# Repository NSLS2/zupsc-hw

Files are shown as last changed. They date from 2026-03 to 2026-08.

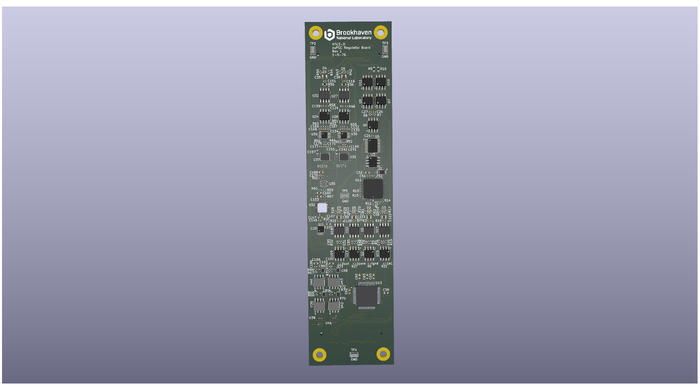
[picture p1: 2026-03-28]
daughter/rev2/psc_daughter_brd.png

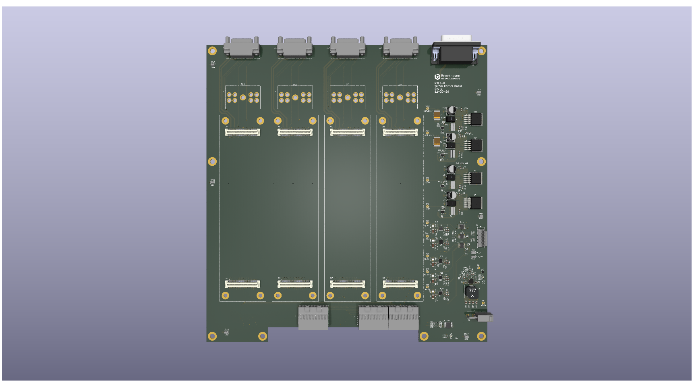
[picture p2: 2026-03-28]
carrier/revA/psc_carrier_brd.png

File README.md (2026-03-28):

# ZuPSC – NSLS-II Power Supply Controller

The **ZuPSC** is the next-generation NSLS-II Power Supply Controller built on a Zynq UltraScale+ FPGA platform. It combines FPGA-based real-time control with embedded software to deliver high-performance regulation, data acquisition, and system diagnostics.
<p align="center">
  <br>
  <em>ZuPSC chassis showing FPGA processing board and channel electronics</em>
</p>

---

## Overview

- **FPGA (PL)**  
  - Executes PID control loops at the sample rate  
  - Handles high-speed data acquisition  
  - Implements interlock and protection logic  

- **ARM Processor (PS)**  
  - Runs a server interface  
  - Communicates with a custom EPICS driver  
  - Provides control, monitoring, and diagnostics over the controls network  

---

## System Architecture

The ZuPSC chassis is composed of three primary circuit boards:

### 1. FPGA Processing Board (zuDFE)
- NSLS-II standard processing platform  
- Digital I/O and GPIO handling  
- ADC data acquisition  
- 20-bit precision DAC output  
- PID control loop execution in FPGA fabric  
- High-speed and low-speed communication:
  - Ethernet
  - Fiber links  
- Embedded Event Receiver (EVR)
  - Compatible with 2.5 Gbps MRF Event Generator (EVG)

---

### 2. Carrier Board
- Interfaces FPGA processing board to channel electronics  
- Routes signals between digital and analog domains  
- Provides system-level connectivity  

---

### 3. Channel Electronics Board
- Precision analog front-end  
- **20-bit DAC** for power supply command output  
- **Dual 20-bit ADCs** for DCCT readback  
- **4× 16-bit ADCs** for auxiliary monitoring  
- Isolated digital I/O channels  

---

## Key Features

- Real-time PID control implemented in FPGA  
- High-resolution (20-bit) DAC/ADC signal chain  
- Deterministic timing via embedded EVR  
- Integrated interlock and protection logic  
- EPICS-compatible control interface  
- Modular 3-board architecture  

---

## Intended Use

The ZuPSC is designed for high-performance accelerator power supply control applications at NSLS-II, where deterministic timing, precision measurement, and reliable interlocks are critical.

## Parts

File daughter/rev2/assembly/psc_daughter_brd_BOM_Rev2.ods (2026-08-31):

zuPSC Daughter Board Rev2
Parts per Board |  | 338
Total Parts Cost |  | $561.68
Do not install parts in red
Line Item | Qty per Board | Unit Cost | Cost Per Board | Part Number | Reference Designator | Value | Description | Manufacturer | DNP
1 | 3 | $0.01 | $0.03 | C0402C100K5RACTU | C21,C26,C27 | 10pF | CAP CER 10PF 50V X7R 0402 | Kemet
2 | 4 | $0.01 | $0.04 | C0402C221K5RACTU | C1,C68,C78,C88 | 220pF | CAP CER 220PF 50V X7R 0402 | Kemet
3 | 4 | $0.01 | $0.04 | GRM1555C1H471FA01D | C120,C122,C128,C129 | 470pF | CAP CER 470PF 50V C0G/NP0 1% 0402 | Kemet
4 | 2 | $0.90 | $1.80 | C0603C202F5GACTU | C111,C112 | 2nF | 2000pF CAP CER 0603 50V 1% NP0/C0G | Kemet
5 | 6 | $0.22 | $1.32 | EMCT101W222M1GV001E | C35,C38,C101,C103,C105,C107 | 2200pF | CAP CER 2200PF 100V X7R 0805 FEED THROUGH | Johanson Dielectrics
6 | 2 | $0.14 | $0.28 | C0603C302J5GACTU | C109,C110 | 3nF | CAP CER 3000PF 25V C0G/NP0 0603 | Murata
7 | 4 | $0.01 | $0.04 | CL05B332KB5NNNC | C116,C141,C151,C176 | 3300pF | CAP CER 3300PF 50V X7R 0402 | Samsung
8 | 4 | $0.01 | $0.04 | CL05B472KB5NNNC | C8,C75,C85,C95 | 4700pF | CAP CER 4700PF 50V X7R 0402 | Samsung
9 | 4 | $0.01 | $0.04 | CL05B682KB5NNNC | C138,C140,C142,C177 | 6800pF | CAP CER 6800PF 50V X7R 0402 | Samsung
10 | 1 | $0.01 | $0.01 | GRM155R71E473KA88D | C132 | 47nF | CAP CER 47nF 25V X7R 0402 | Murata
11 | 85 | $0.01 | $0.85 | TMK105BJ104KV-F | C4,C5,C9,C10,C13,C14,C16,C19,C20,C24,C25,C29,C34,C36,C37,C39,C44,C45,C46,C47,C48,C50,C51,C53,C54,C55,C56,C58,C64,C65,C67,C71,C72,C76,C77,C81,C82,C86,C87,C91,C92,C96,C97,C99,C102,C104,C108,C113,C115,C117,C123,C124,C126,C130,C134,C137,C144,C146,C148,C149,C150,C152,C158,C159,C163,C164,C165,C168,C170,C173,C174,C175,C179,C181,C182,C183,C184,C185,C186,C189,C190,C191,C192,C193,C196 | 0.1uF | CAP CER 0.1UF 25V X5R 0402 | Taiyo Yuden
12 | 1 | $0.01 | $0.01 | CL10B105KA8NNNC | C49 | 1uF | CAP CER 1UF 25V X7R 0603 | Samsung
13 | 1 | $0.18 | $0.18 | CGA4J1X7R1H475K125AC | C131 | 4.7uF | CAP CER 4.7UF 50V X7R 0805 | Samsung
14 | 74 | $0.07 | $5.18 | CL10A106MA8NRNC | C2,C3,C6,C7,C11,C12,C15,C17,C18,C22,C23,C28,C30,C31,C32,C33,C40,C41,C42,C43,C52,C57,C59,C60,C61,C62,C63,C66,C69,C70,C73,C74,C79,C80,C83,C84,C89,C90,C93,C94,C98,C100,C106,C114,C118,C119,C121,C125,C127,C133,C136,C139,C143,C145,C147,C153,C154,C155,C156,C157,C160,C161,C162,C166,C167,C169,C171,C172,C178,C180,C187,C188,C194,C195 | 10uF | CAP CER 10UF 25V X5R 0603 | Samsung
15 | 1 | $0.62 | $0.62 | MSAST32MAB5476MPNDT1 | C135 | 47uF | CAP CER 047UF 25V X5R 1210 | Taiyo Yuden
16 | 2 | $2.53 | $5.06 | 61082-061400LF | J1,J2 |  | CONN RCPT 60POS SMD GOLD | Amphenol
17 | 1 | $0.23 | $0.23 | DFLS130-7 | D1 |  | DIODE SCHOTTK 30V 1A POWERDI 123 | Diodes Inc.
18 | 2 | $34.72 | $69.44 | LTC2376CDE-20#PBF | U31,U37 |  | IC ADC 20BIT SAR 16DFN | Analog Devices
19 | 1 | $125.06 | $125.06 | ADR1001AEZ | U12 |  | IC VREF SERIES 5V 0.25% 20CLCC | Analog Devices
20 | 3 | $4.51 | $13.53 | LT6202CS5#TRPBF | U22,U24,U35 |  | IC OPAMP GP 1 CIRCUIT TSOT23-5 | Analog Devices
21 | 1 | $14.02 | $14.02 | LTC6655BHLS8-5#PBF | U32 |  | IC VREF SERIES 0.025% 8CLCC | Analog Devices
22 | 2 | $0.77 | $1.54 | TXUN0104RUTR | U38,U41 |  | IC XLTR VL UNIDIR 12-UQFN | TI
23 | 1 | $25.17 | $25.17 | ADS8568SPM | U13 |  | IC ADC 16BIT SAR 64LQFP | Analog Devices
24 | 2 | $6.81 | $13.62 | ADUM5240ARZ | U39,U40 |  | DGTL ISOLTR 2.5KV 2CH GP 8-SOIC | Analog Devices
25 | 2 | $6.81 | $13.62 | ADUM5242ARZ | U42,U43 |  | DGTL ISOLTR 2.5KV 2CH GP 8-SOIC | Analog Devices
26 | 1 | $2.72 | $2.72 | ADA4523-1BRMZ | U23 |  | IC OPAMP ZER-DRIFT 1CIRC 8MSOP | Analog Devices
27 | 4 | $10.23 | $40.92 | AD8221BRZ | U1,U14,U16,U18 |  | IC INST AMP 1 CIRCUIT 8SOIC | Analog Devices
28 | 2 | $12.76 | $25.52 | AD8429BRZ | U27,U33 |  | IC INST AMP 1 CIRCUIT 8SOIC | Analog Devices
29 | 2 | $3.46 | $6.92 | THP210DR | U21,U26 |  | IC OPAMP DIFF 1 CIRCUIT 8SOIC | TI
30 | 4 | $0.65 | $2.60 | SP3006-02XTG | CR5,CR6,CR7,CR8 |  | TVS DIODE 6VWM 15VC SOT563 | Littlefuse
31 | 6 | $0.24 | $1.44 | SP3118-01ETG | D2,D3,D4,D5,D6,D7 |  | TVS DIODE 18VWM 38VC SOD882 | Littlefuse
32 | 4 | $0.23 | $0.92 | RCS-0C | TP2,TP3,TP4,TP5 |  | PC TEST POINT NATURAL | TE
33 | 1 | $4.96 | $4.96 | LT3042EMSE#TRPBF | U20 |  | IC REG LINEAR POS ADJ 10MSOP-EP | Analog Devices
34 | 6 | $2.66 | $15.96 | OPA277UA/2K5 | U2,U7,U9,U15,U17,U19 |  | IC OPAMP GP 1 CIRCUIT 8SOIC | Analog Devices
35 | 1 | $3.93 | $3.93 | AD8676ARZ-REEL7 | U3 |  | IC OPAMP GP 2 CIRCUIT 8SOIC | Analog Devices
36 | 2 | $5.91 | $11.82 | AD8676BRZ | U4,U8 |  | IC OPAMP GP 2 CIRCUIT 8SOIC | Analog Devices
37 | 1 | $13.75 | $13.75 | AD797ARZ | U6 |  | IC OPAMP GP 1 CIRCUIT 8SOIC | Analog Devices
38 | 2 | $2.99 | $5.98 | BUF634AIDR | U10,U11 |  | IC OPAMP GP 1 CIRCUIT 8SOIC | Analog Devices
39 | 1 | $129.29 | $129.29 | AD5791BRUZ | U5 |  | IC DAC 20BIT V-OUT 20TSSOP | Analog Devices
40 | 2 | $0.10 | $0.20 | BAT54S | D8,D9 |  | DIODE ARR SCHOTT 30V 200MA SOT23 | Diotec Semi
41 | 2 | $0.07 | $0.14 | LTST-C191KGKT | D10,D11 |  | LED GREEN CLEAR SMD | Lite-On Inc.
42 | 5 | $0.01 | $0.05 | ERJ-2GE0R00X | R15,R49,R79,R82,R83 | 0 | RES SMD 0 OHM JUMPER 1/10W 0402 | Panasonic
43 | 1 | $0.28 | $0.28 | RNCA0805BTS2K00 | R76 | 2 | RES 0805 2 OHM 0.1% | Stackpole
44 | 4 | $0.01 | $0.04 | ERJ-2RKF10R0X | R3,R18,R24,R30 | 10 | RES SMD 10 OHM 1% 1/10W 0402 | Panasonic | DNP
45 | 7 | $0.01 | $0.07 | ERJ-2RKF10R0X | R6,R12,R21,R27,R33,R61,R80 | 10 | RES SMD 10 OHM 1% 1/10W 0402 | Panasonic
46 | 4 | $0.01 | $0.04 | ERJ-2RKF30R1X | R52,R53,R64,R65 | 30.1 | RES SMD 30.1 OHM 1% 1/10W 0402 | Panasonic
47 | 2 | $0.01 | $0.02 | ERJ-2RKF15R0X | R9,R10 | 100 | RES SMD 100 OHM 1% 1/3W 0603 | Panasonic
48 | 1 | $0.01 | $0.01 | ERJ-2RKF1200X | R11 | 120 | RES SMD 120 OHM 1% 1/10W 0402 | Panasonic
49 | 2 | $0.32 | $0.64 | RQ73C1J665RBTD | R36,R56 | 665 | RES 665 OHMS 0.1% 0.15W 0603 | TE
50 | 1 | $0.38 | $0.38 | ERA-2ARB751X | R74 | 750 | RES SMD 750 OHM 0.1% 1/16W 0402 | Panasonic
51 | 12 | $0.01 | $0.12 | ERJ-2RKF1001X | R1,R2,R16,R17,R22,R23,R28,R29,R42,R43,R54,R55 | 1.0K | RES SMD 1K OHM 1% 1/10W 0402 | Panasonic
52 | 1 | $0.38 | $0.38 | ERA-2ARB102X | R50 | 1K | RES SMD 1K OHM 0.1% 1/16W 0402 | Panasonic
53 | 2 | 0.01 | $0.02 | ERJ-2RKF2200X | R57,R84 | 2.2K | RES SMD 220 OHM 1% 1/10W 0402 | Panasonic
54 | 8 | $0.01 | $0.08 | ERJ-2RKF2491X | R66,R67,R68,R69,R70,R71,R72,R73 | 2.49K | RES SMD 2.49K OHM 1% 1/10W 0402 | Panasonic
55 | 2 | $0.01 | $0.02 | ERJ-2RKF5111X | R7,R8 | 5.11K | RES SMD 5.11K OHM 1% 1/10W 0402 | Panasonic
56 | 1 | $0.38 | $0.38 | ERA-2ARB5621X | R75 | 5.62k | RES SMD 5.62KOHM 0.1% 1/16W 0402 | Panasonic
57 | 8 | $0.01 | $0.08 | ERJ-2RKF1002X | R4,R5,R19,R20,R25,R26,R31,R32 | 10K | RES SMD 10K OHM 1% 1/10W 0402 | Panasonic
58 | 19 | $0.01 | $0.19 | RT0603BRB0710KL | R35,R37,R38,R39,R40,R41,R44,R45,R46,R47,R48,R51,R58,R59,R60,R62,R63,R77,R78 | 10.0K | RES SMD 10K OHM 0.1% 1/10W 0603 | Yageo
59 | 1 | $0.01 | $0.01 | ERA-3ARB203V | R81 | 20.0K | RES SMD 20K OHM 0.1% 1/10W 0603 | Panasonic
60 | 1 | $0.01 | $0.01 | ERJ-2RKF6342X | R13 | 63K | RES SMD 63.4K OHM 1% 1/10W 0402 | Panasonic | DNP
61 | 1 | $0.01 | $0.01 | ERJ-2RKF7872X | R14 | 78.7K | RES SMD 78.7K OHM 1% 1/10W 0402 | Panasonic
62 | 1 | $0.01 | $0.01 | ERJ-2RKF1213X | R34 | 121K | RES SMD 121K OHM 1% 1/10W 0402 | Panasonic

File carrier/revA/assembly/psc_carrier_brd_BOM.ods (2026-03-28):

zuPSC Carrier Board
Parts Per Board |  | 216
Total Parts Cost |  | $304.54
Line Number | Qty per Board | Unit Cost | Cost Per Board | Part Number | Reference | Value | Description | Manufacturer
1 | 4 | $6.06 | $24.24 | LT3045EDD#TRPBF | U7,U8,U9,U10 |  | IC REG LIN POS ADJ 500MA 10DFN | Analog Devices
2 | 4 | $2.01 | $8.04 | LT6106CS5#TRMPBF | U4,U5,U21,U22 |  | IC CURR SENSE 1 CIRCUIT TSOT23-5 | Analog Devices
3 | 2 | $6.46 | $12.92 | LT3015EQ-15#PBF | U3,U20 |  | IC REG LINEAR -15V 1.5A DDPAK-5 | Analog Devices
4 | 2 | $5.57 | $11.14 | LT1963AEQ#TRPBF | U2,U19 |  | IC REG LIN POS ADJ 1.5A DDPAK-5 | Analog Devices
5 | 4 | $0.00 | $0.00 | BNL | U15,U16,U17,U18 |  | Burden Resistor Daughterboard | BNL
6 | 3 | $9.38 | $28.14 | LTC2991CMS#TRPBF | U12,U13,U14 |  | IC MONITOR OCTAL 16MSOP | Analog Devices
7 | 1 | $0.37 | $0.37 | CD74HC4050PWR | U23 |  | IC BUFFER NON-INVERT 6V 16-TSSOP | TI
8 | 1 | $9.56 | $9.56 | LT8643SEV#PBF | U11 |  | IC REG BUCK ADJ 6A 24LQFN | Analog Devices
9 | 1 | $5.79 | $5.79 | LT3015EDD#PBF | U6 |  | IC REG LINEAR NEG ADJ 1.5A 8-DFN | Analog Devices
10 | 1 | $1.78 | $1.78 | 3-641215-6 | U1 |  | CONN HEADER VERT 6POS 2.54MM | TE
11 | 8 | $0.23 | $1.84 | RCS-0C | TP12,TP13,TP14,TP15,TP16,TP17,TP18,TP19 |  | PC TEST POINT NATURAL | TE
12 | 11 | $0.00 | $0.00 | N/A | TP1,TP2,TP3,TP4,TP5,TP6,TP7,TP8,TP9,TP10,TP11 |  | TEST POINT | N/A
13 | 6 | $0.01 | $0.06 | ERJ-2RKF4991X | R9,R10,R48,R49,R58,R59 | 4.99K | RES SMD 4.99K OHM 1% 1/10W 0402 | Panasonic
14 | 11 | $0.01 | $0.11 | ERJ-2RKF1002X | R60,R61,R62,R63,R64,R65,R66,R67,R68,R69,R70 | 10K | RES SMD 9.53K OHM 1% 1/10W 0402 | Panasonic
15 | 3 | $0.01 | $0.03 | ERJ-2RKF9531X | R42,R44,R46 | 9.53K | RES SMD 9.53K OHM 1% 1/10W 0402 | Panasonic
16 | 4 | $0.71 | $2.84 | KRL6432E-M-R010-F-T1 | R4,R7,R53,R56 | 0.01 | RES 0.01 OHM 3W 2512 WIDE | Susumu
17 | 6 | $0.01 | $0.06 | ERJ-2RKF9091X | R36,R38,R40,R43,R45,R47 | 9.09K | RES SMD 9.09K OHM 1% 1/10W 0402 | Panasonic
18 | 2 | $0.01 | $0.02 | ERJ-2RKF4701X | R31,R32 | 4.7K | RES SMD 4.7K OHM 1% 1/10W 0402 | Panasonic
19 | 8 | $0.01 | $0.08 | ERJ-2RKF1000X | R3,R5,R6,R8,R52,R54,R55,R57 | 100 | RES SMD 100 OHM 1% 1/10W 0402 | Panasonic
20 | 2 | $0.01 | $0.02 | ERJ-2RKF1022X | R29,R35 | 10.2K | RES SMD 10.2K OHM 1% 1/10W 0402 | Panasonic
21 | 7 | $0.01 | $0.07 | ERJ-2RKF1001X | R2,R16,R27,R37,R39,R41,R51 | 1.0K | RES SMD 1K OHM 1% 1/10W 0402 | Panasonic
22 | 5 | $0.38 | $1.90 | KRL2012E-M-R220-F-T5 | R13,R14,R19,R22,R25 | 0.22 | RES 0.22 OHM 1W 0805 WIDE | Susumu
23 | 5 | $0.01 | $0.05 | ERJ-2GE0R00X | R11,R17,R20,R23,R33 | 0 | RES SMD 0 OHM JUMPER 1/10W 0402 | Panasonic
24 | 3 | $0.01 | $0.03 | ERJ-2RKF1152X | R1,R15,R50 | 11.5K | ERJ-2RKF1152X | Panasonic
25 | 1 | $0.01 | $0.01 | ERJ-2RKF1600X | R71 | 160 | RES SMD 160 OHM 1% 1/10W 0402 | Panasonic
26 | 1 | $0.01 | $0.01 | ERJ-2RKF4222X | R34 | 42.2K | RES SMD 42.2K OHM 1% 1/10W 0402 | Panasonic
27 | 1 | $0.01 | $0.01 | ERJ-2RKF1131X | R30 | 1.13K | RES SMD 1.13K OHM 1% 1/10W 0402 | Panasonic
28 | 1 | $0.01 | $0.01 | ERJ-2RKF8451X | R28 | 8.45K | RES SMD 8.45K OHM 1% 1/10W 0402 | Panasonic
29 | 1 | $0.01 | $0.01 | ERJ-2RKF4122X | R26 | 41.2K | RES SMD 41.2K OHM 1% 1/10W 0402 | Panasonic
30 | 1 | $0.01 | $0.01 | ERJ-2RKF2492X | R24 | 24.9K | RES SMD 24.9K OHM 1% 1/10W 0402 | Panasonic
31 | 1 | $0.01 | $0.01 | ERJ-2RKF1802X | R21 | 18.0K | RES SMD 18K OHM 1% 1/10W 0402 | Panasonic
32 | 1 | $0.01 | $0.01 | ERJ-2RKF3322X | R18 | 33.2K | RES SMD 33.2K OHM 1% 1/10W 0402 | Panasonic
33 | 1 | $0.01 | $0.01 | ERJ-2RKF5362X | R12 | 53.6K | RES SMD 53.6K OHM 1% 1/10W 0402 | Panasonic
34 | 1 | $0.10 | $0.10 | NX7002BKWX | Q1 |  | MOSFET N-CH 60V 270MA SOT323 | Nexperia
35 | 5 | $0.01 | $0.05 | LSMGG160808T331RG | L1,L2,L3,L4,L5 |  | FERRITE BEAD 330 OHM 0603 1LN | Taiyo Yuden
36 | 1 | $3.26 | $3.26 | MSS1048-222NLC | L6 | 2.2uF | FIXED IND 2.2UH 9.78A 7.2MOHM SM | Coilcraft
37 | 4 | $17.82 | $71.28 | 836149012 | J8,J11,J14,J17 |  | CONN MICRO-D PLUG 25POS R/A SLDR | Molex
38 | 8 | $2.81 | $22.48 | 61083-061402LF | J5,J6,J9,J10,J12,J13,J15,J16 |  | CONN PLUG 60POS SMD GOLD | Amphenol
39 | 3 | $17.37 | $52.11 | 6469028-1 | J1,J2,J3 |  | CONN RCPT HIGH SPEED 60P EDGE MT | TE
40 | 1 | $24.50 | $24.50 | 1731130154 | J7 |  | CONN D-SUB HD PLG 26POS R/A SLDR | Molex
41 | 1 | $1.25 | $1.25 | 39301022 | J4 |  | CONN HEADER R/A 2POS | Molex
42 | 2 | $0.77 | $1.54 | ASMDC300F/24-2 | F1,F2 |  | PTC RESET FUSE 24V 3A 2SMD | Littlefuse
43 | 2 | $0.10 | $0.20 | LTST-C191KGKT | D1,D3 | GREEN | LED GREEN CLEAR SMD | Lite-On Inc.
44 | 4 | $3.56 | $14.24 | T521X107M025ATE060 | C7,C8,C66,C67 | 100uF | CAP TANT POLY 100UF 25V 2917 | Kemet
45 | 4 | $0.04 | $0.16 | CL21A226MAYNNNE | C53,C54,C55,C56 | 22uF | CAP CER 22UF 25V X5R 0805 | Samsung
46 | 28 | $0.01 | $0.28 | TMK105BJ104KV-F | C5,C6,C10,C12,C13,C14,C15,C19,C21,C23,C24,C30,C31,C36,C37,C42,C43,C57,C58,C59,C64,C65,C69,C71,C72,C73,C74,C75 | 0.1uF | CAP CER 0.1UF 25V X5R 0402 | Taiyo Yuden
47 | 2 | $0.01 | $0.02 | CL10C100JB8NFNC | C48,C52 | 10pF | CAP CER 10PF 50V C0G/NP0 0603 | Samsung
48 | 25 | $0.04 | $1.00 | CL10A106MA8NRNC | C3,C4,C9,C11,C16,C17,C18,C20,C22,C25,C28,C29,C32,C34,C35,C38,C40,C41,C44,C47,C49,C62,C63,C68,C70 | 10uF | CAP CER 10UF 25V X5R 0603 | Samsung
49 | 5 | $0.22 | $1.10 | GRM31CR61A107MEA8L | C26,C27,C33,C39,C45 | 100uF | CAP CER 100UF 10V X5R 1206 | Murata
50 | 4 | $0.44 | $1.76 | EEE-FTH101XAP | C1,C2,C60,C61 | 100uF | CAP ALUM 100UF 20% 50V SMD | Panasonic
51 | 1 | $0.01 | $0.01 | CL10B105KA8NNNC | C51 | 1uF | CAP CER 1UF 25V X7R 0603 | Samsung
52 | 1 | $0.01 | $0.01 | CL10B331KB8NNNC | C50 | 330pF | CAP CER 330PF 50V X7R 0603 | Samsung
53 | 1 | $0.01 | $0.01 | CL10B223KB8NNNC | C46 | 0.022uF | CAP CER 0.022UF 50V X7R 0603 | Samsung

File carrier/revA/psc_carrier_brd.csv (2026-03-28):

Id | Designator | Footprint | Quantity | Designation | Supplier and ref
1 | C67,C66,C8,C7 | CAPMP7.6X4.3_4.3N_KEM | 4 | 100uF
2 | C61,C60,C1,C2 | CAP_EEFK_D8_PAN | 4 | 100uF
3 | U1 | 3-641215-6_TYC | 1 | 3-641215-6
4 | J1,J2,J3 | TE_6469028-1 | 3 | 6469028-1
5 | R16,R2,R51 | R_0402_1005Metric | 3 | 1.0K
6 | R13,R14,R22,R19,R25 | RESC1220X70N | 5 | KRL2012E-M-R220-F-T5
7 | U9,U7,U8,U10 | DFN-10-1EP_3x3mm_P0.5mm_EP1.65x2.38mm | 4 | LT3045xDD
8 | C20,C32,C3,C44,C16,C63,C28,C68,C18,C25,C41,C22,C17,C11,C29,C40,C70,C62,C35,C34,C4,C38,C9 | C_0603_1608Metric | 23 | 10uF
9 | L5,L2,L3,L1,L4 | IND_LSMG_160808_TAY | 5 | LSMGG160808T331RG
10 | R64,R66,R62,R69,R67,R61,R63,R60,R65,R68 | R_0402_1005Metric | 10 | 10K
11 | U19,U2 | TO-263-5_TabPin3 | 2 | LT1963AEQ
12 | R48,R58,R49,R10,R9,R59 | R_0402_1005Metric | 6 | 4.99K
13 | D1 | LED_0603_1608Metric | 1 | GREEN
14 | R27 | R_0402_1005Metric | 1 | 1k
15 | R26 | R_0402_1005Metric | 1 | 41.2k
16 | U17,U16,U15,U18 | burden | 4 | ~
17 | R15,R50,R1 | R_0402_1005Metric | 3 | 11.4K
18 | R28 | R_0402_1005Metric | 1 | 8.45k
19 | R33,R20,R23,R11,R17 | R_0402_1005Metric | 5 | 0
20 | R32,R31 | R_0402_1005Metric | 2 | 4.7k
21 | U13,U14,U12 | MSOP-16_MS | 3 | LTC2991CMS_TRPBF
22 | C31,C30,C65,C24,C6,C42,C10,C36,C37,C23,C21,C19,C12,C71,C5,C69,C64,C43,C58,C14,C75,C13,C72,C74,C15,C59,C73,C57 | C_0402_1005Metric | 28 | 0.1uF
23 | R56,R53,R4 | RES_6432_SUS | 3 | KRL6432E-M-R010-F-T1
24 | J15,J10,J9,J12,J5,J16,J13,J6 | AMPHENOL_61083-061402LF | 8 | 61083-061402LF
25 | R29,R35 | R_0402_1005Metric | 2 | 10.2k
26 | U11 | QFN-24-4EP_4x4mm_P0.5mm_EP1.125x1.125mm | 1 | LT8643S
27 | R12 | R_0402_1005Metric | 1 | 53K
28 | R36,R38,R45,R43,R47,R40 | R_0402_1005Metric | 6 | 9K
29 | R46,R42,R44 | R_0402_1005Metric | 3 | 9.56K
30 | C27,C33,C26,C39,C45 | C_1206_3216Metric | 5 | 100uF
31 | C48,C52 | C_0603_1608Metric | 2 | 10p
32 | R55,R54,R57,R5,R3,R8,R6,R52 | R_0402_1005Metric | 8 | 100
33 | TP2 | TestPoint_THTPad_D2.0mm_Drill1.0mm | 1 | +5.0V
34 | R34 | R_0402_1005Metric | 1 | 42.2k
35 | R39,R41,R37 | R_0402_1005Metric | 3 | 1K
36 | J11,J17,J14,J8 | 0836149012 | 4 | 0836149012
37 | U4,U21,U5,U22 | SOT-23-5 | 4 | LT6105
38 | C56,C54,C55,C53 | C_0805_2012Metric | 4 | 22u
39 | C46 | C_0603_1608Metric | 1 | 0.022u
40 | C49,C47 | C_0603_1608Metric | 2 | 10u
41 | L6 | COILCRAFT_MSS1048 | 1 | 2.2u
42 | U20,U3 | TO-263-5_TabPin3 | 2 | LT3015xQ-15
43 | R18 | R_0402_1005Metric | 1 | 33.2K
44 | U23 | PW16 | 1 | CD74HC4050
45 | J4 | MOLEX_39301022 | 1 | 39301022
46 | R30 | R_0402_1005Metric | 1 | 1.13k
47 | U6 | DFN-8_DD | 1 | LT3015EDDPBF
48 | R7 | RES_6432_SUS | 1 | 0.01
49 | Q1 | SOT-323_SC-70 | 1 | NX7002BKW
50 | TP1 | TestPoint_THTPad_D2.0mm_Drill1.0mm | 1 | Net-(Q1-G)
51 | R21 | R_0402_1005Metric | 1 | 18.0K
52 | C51 | C_0603_1608Metric | 1 | 1u
53 | C50 | C_0603_1608Metric | 1 | 330p
54 | R24 | R_0402_1005Metric | 1 | 24.9K
55 | J7 | CONN_F15-26P135G0-5979_MOL | 1 | 1731130154

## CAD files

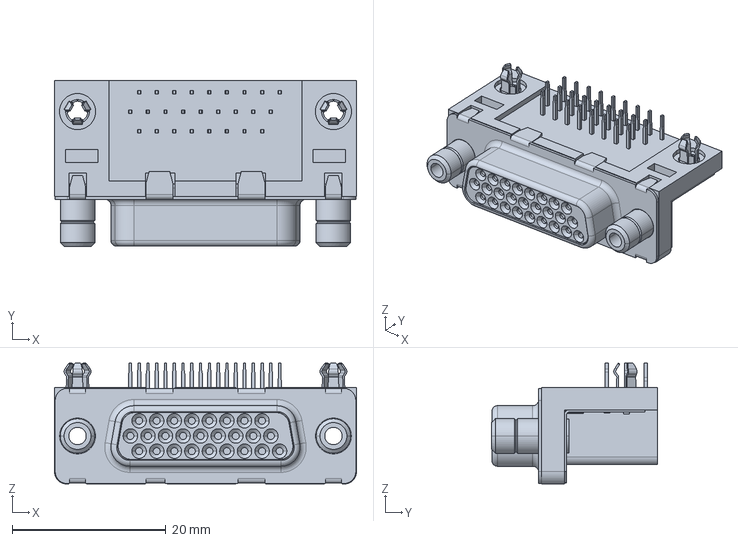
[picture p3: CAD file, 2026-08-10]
carrier/revA/3dmodels/ICD26S13E6GV00LF.STEP
39.3 x 21.6 x 15.8 mm

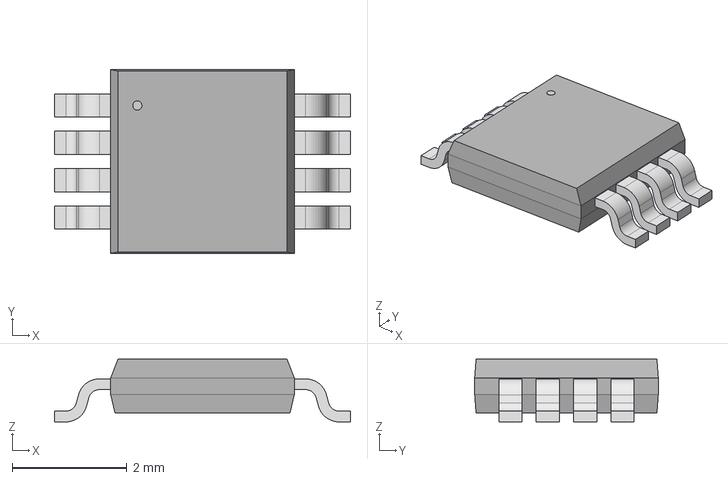
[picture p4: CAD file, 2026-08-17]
daughter/rev2/3dmodels/RM-8_ADI.step
5.16 x 3.20 x 1.09 mm

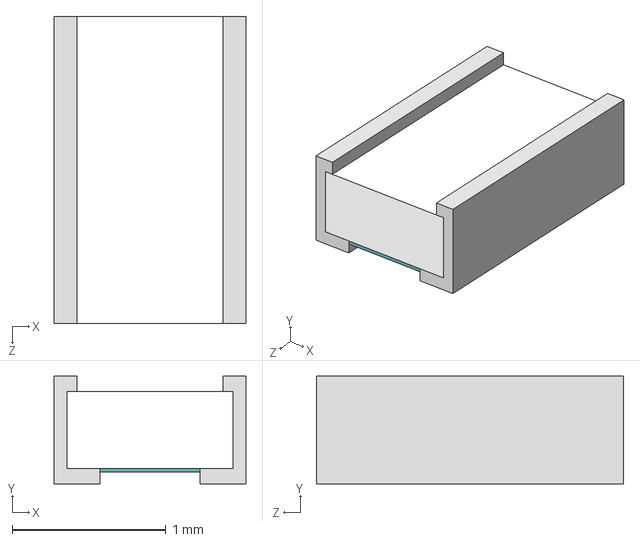
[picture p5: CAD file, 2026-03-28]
carrier/revA/3dmodels/KRL2012E-M-R220-F-T5.step
1.25 x 0.7 x 2.00 mm

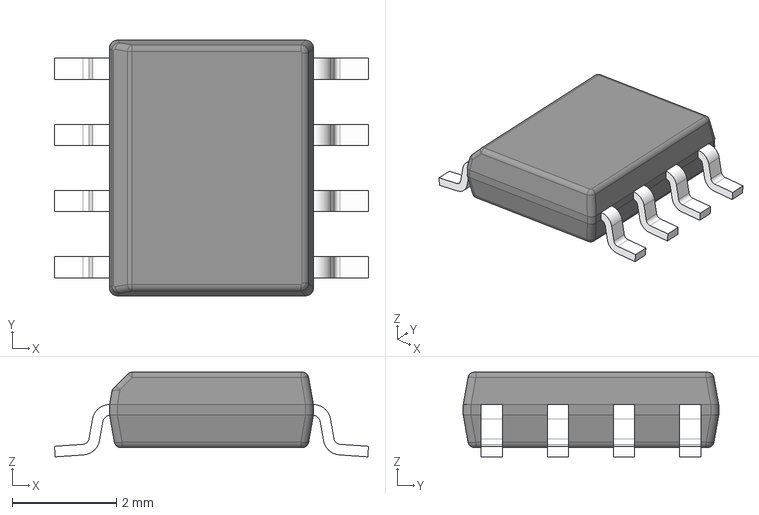
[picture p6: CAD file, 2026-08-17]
daughter/rev2/3dmodels/D0008A.stp
6.02 x 4.90 x 1.63 mm
BODY-SO
LEAD-D0008A x 8

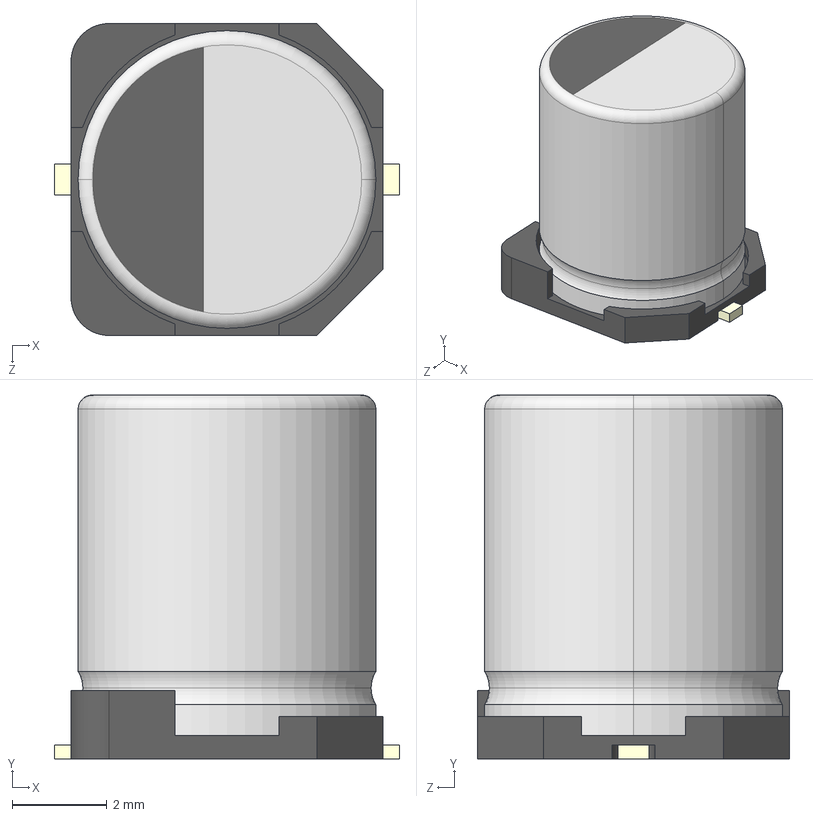
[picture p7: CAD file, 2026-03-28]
carrier/revA/3dmodels/EEE-FTH101XAP.step
7.30 x 7.70 x 6.60 mm
標準SIZE CODE D8-001
標準SIZE CODE D8-002
標準SIZE CODE D8-003 x 2

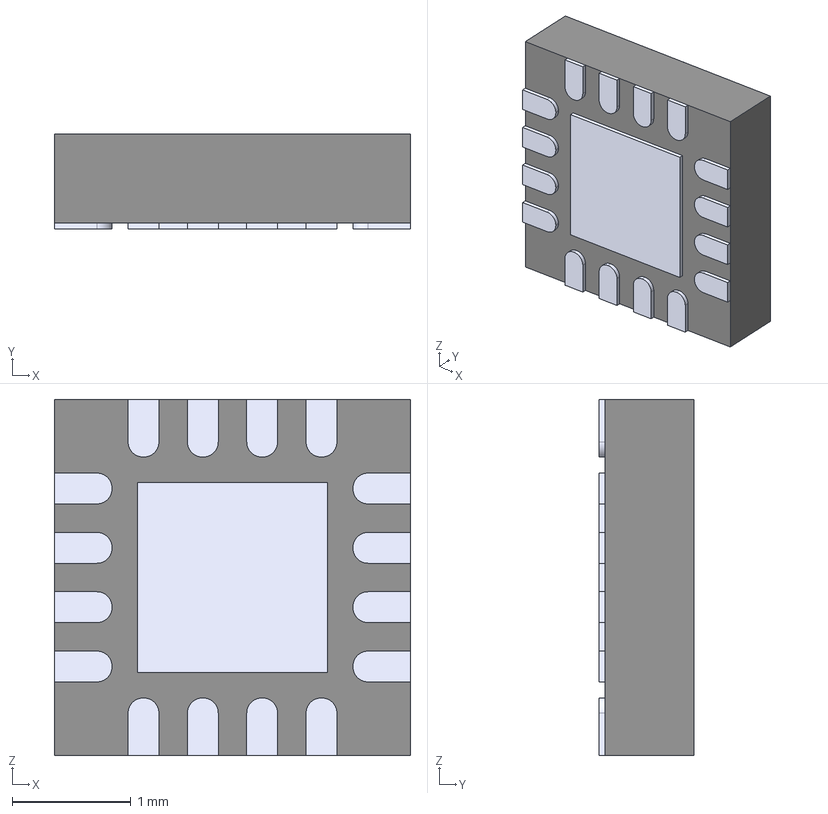
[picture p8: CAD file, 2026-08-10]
daughter/rev2/3dmodels/ADA4945-1ACPZ-R7.step
3.00 x 0.8 x 3.00 mm
BaseWithTopCut
TopCircle_NewBody

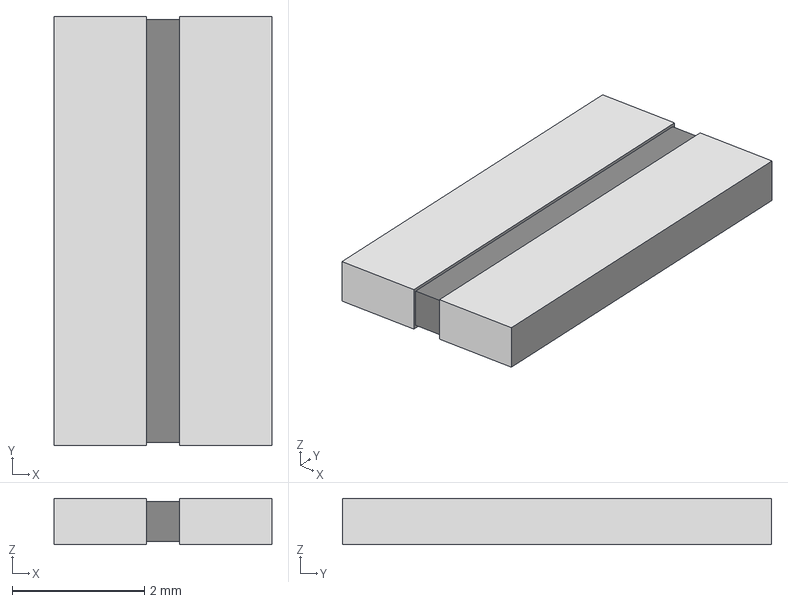
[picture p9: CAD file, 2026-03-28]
carrier/revA/3dmodels/RES_6432_SUS.step
3.30 x 6.50 x 0.7 mm

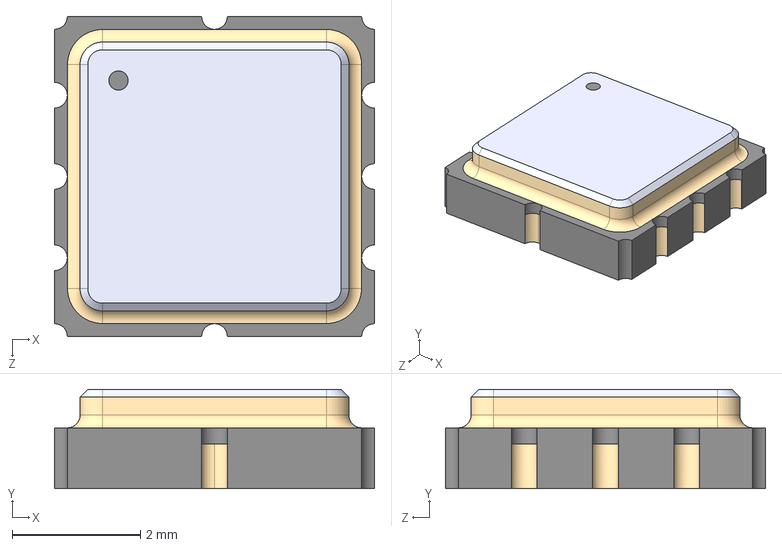
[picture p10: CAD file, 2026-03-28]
daughter/rev2/3dmodels/LTC6655BHLS8-5#PBF.STEP
5.00 x 1.55 x 5.00 mm

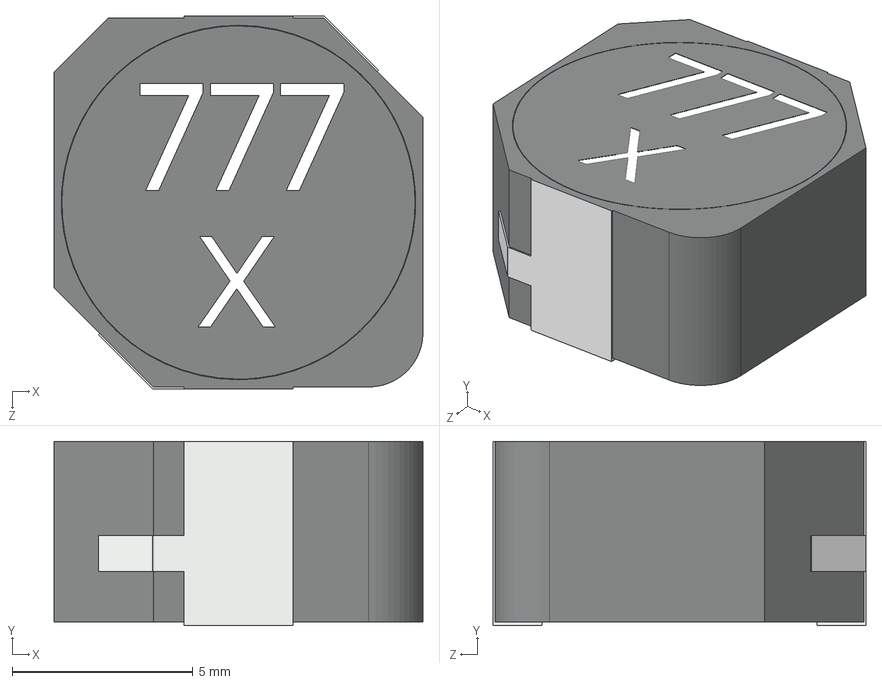
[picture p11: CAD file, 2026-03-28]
carrier/revA/3dmodels/Coilcraft-MSS1048.step
10.2 x 5.10 x 10.3 mm

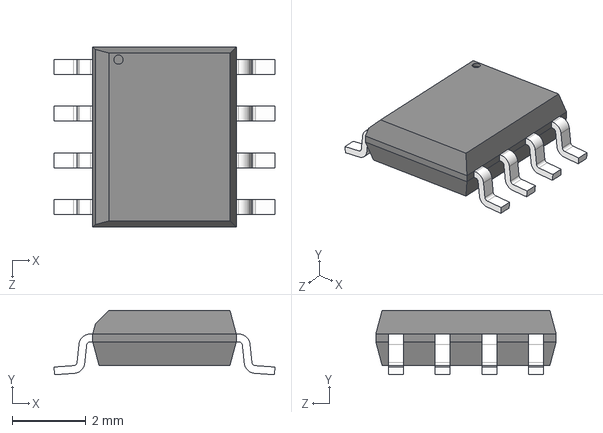
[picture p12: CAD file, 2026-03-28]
daughter/rev2/3dmodels/AD8221BRZ.STEP
6.00 x 1.75 x 4.90 mm

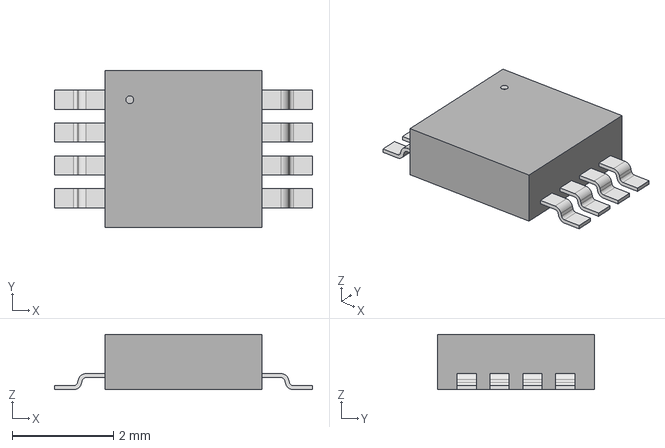
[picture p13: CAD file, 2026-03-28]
carrier/revA/3dmodels/MSOP-8_MS_LIT.step
5.11 x 3.10 x 1.09 mm

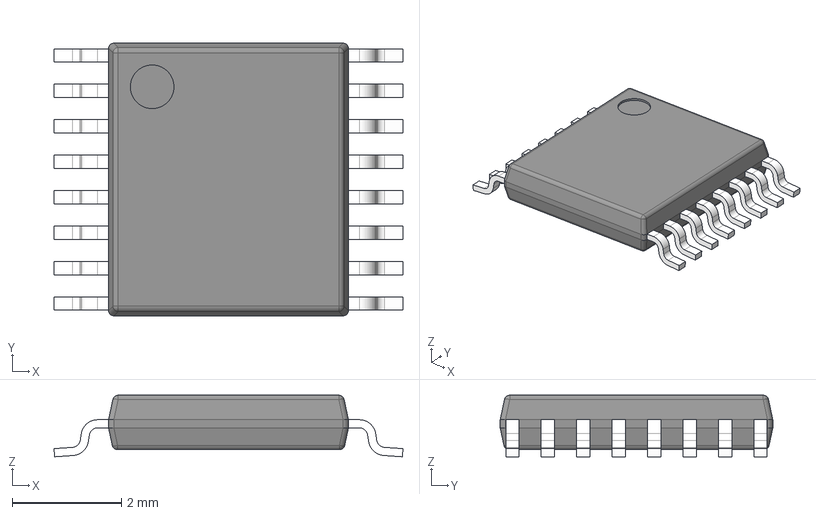
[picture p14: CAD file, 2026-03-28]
carrier/revA/3dmodels/PW0016A.step
6.40 x 5.00 x 1.13 mm
BODY-TSSOP
LEAD-TSSOP x 16
PIN1

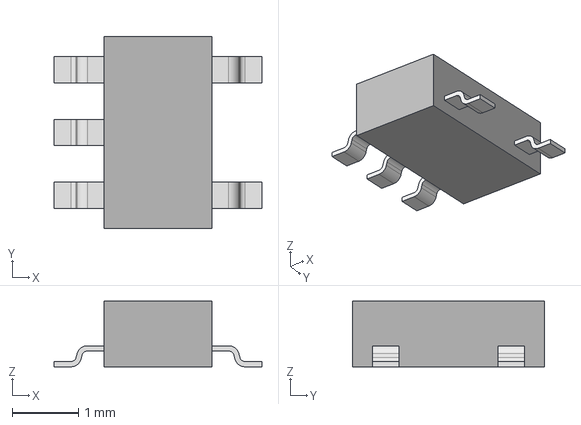
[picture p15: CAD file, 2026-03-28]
daughter/rev2/3dmodels/S_5_ADI.step
3.14 x 2.90 x 0.991 mm

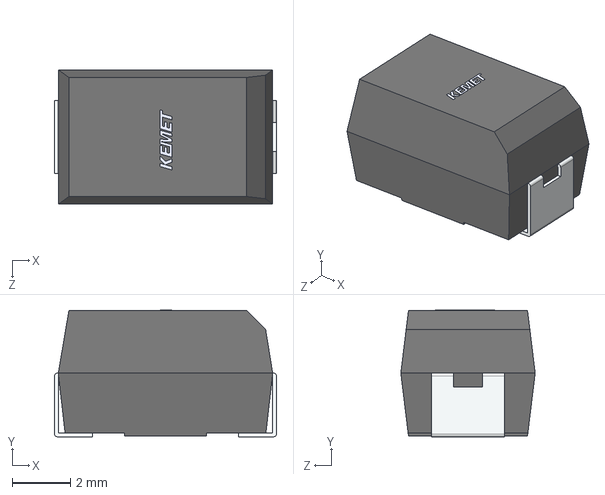
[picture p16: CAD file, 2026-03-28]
carrier/revA/3dmodels/T521X107M025ATE060.step
7.60 x 4.34 x 4.60 mm

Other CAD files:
daughter/rev2/3dmodels/DFLS130-7_DIO.step
carrier/revA/3dmodels/IND_LSMG_160808_TAY.step
carrier/revA/3dmodels/LTC2991CMS_TRPBF.step
daughter/rev2/3dmodels/RUT0012A.stp
carrier/revA/3dmodels/3-641215-6-z-3d.step
carrier/revA/3dmodels/FUSE_SMDC300F24-2_LTF.step
carrier/revA/3dmodels/LT3015EDDPBF.step
daughter/rev2/3dmodels/39301022.step
daughter/rev2/3dmodels/61082-061400LF--3DModel-STEP-740395.STEP
daughter/rev2/3dmodels/61082-061400LF.step
daughter/rev2/3dmodels/6469028-1.step
daughter/rev2/3dmodels/836149012.step
daughter/rev2/3dmodels/ADS8568SPM.step
daughter/rev2/3dmodels/Amphenol_10090926-P264XLF.step
daughter/rev2/3dmodels/E-20-1_ADI.step
daughter/rev2/3dmodels/LTC2378CDE-20#PBF.STEP
daughter/rev2/3dmodels/R_8_ADI.step
daughter/rev2/3dmodels/SOT563_LTF.step
daughter/rev2/3dmodels/c-1625854-1-ba-3d.step

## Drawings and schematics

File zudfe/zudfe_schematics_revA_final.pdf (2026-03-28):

B

B

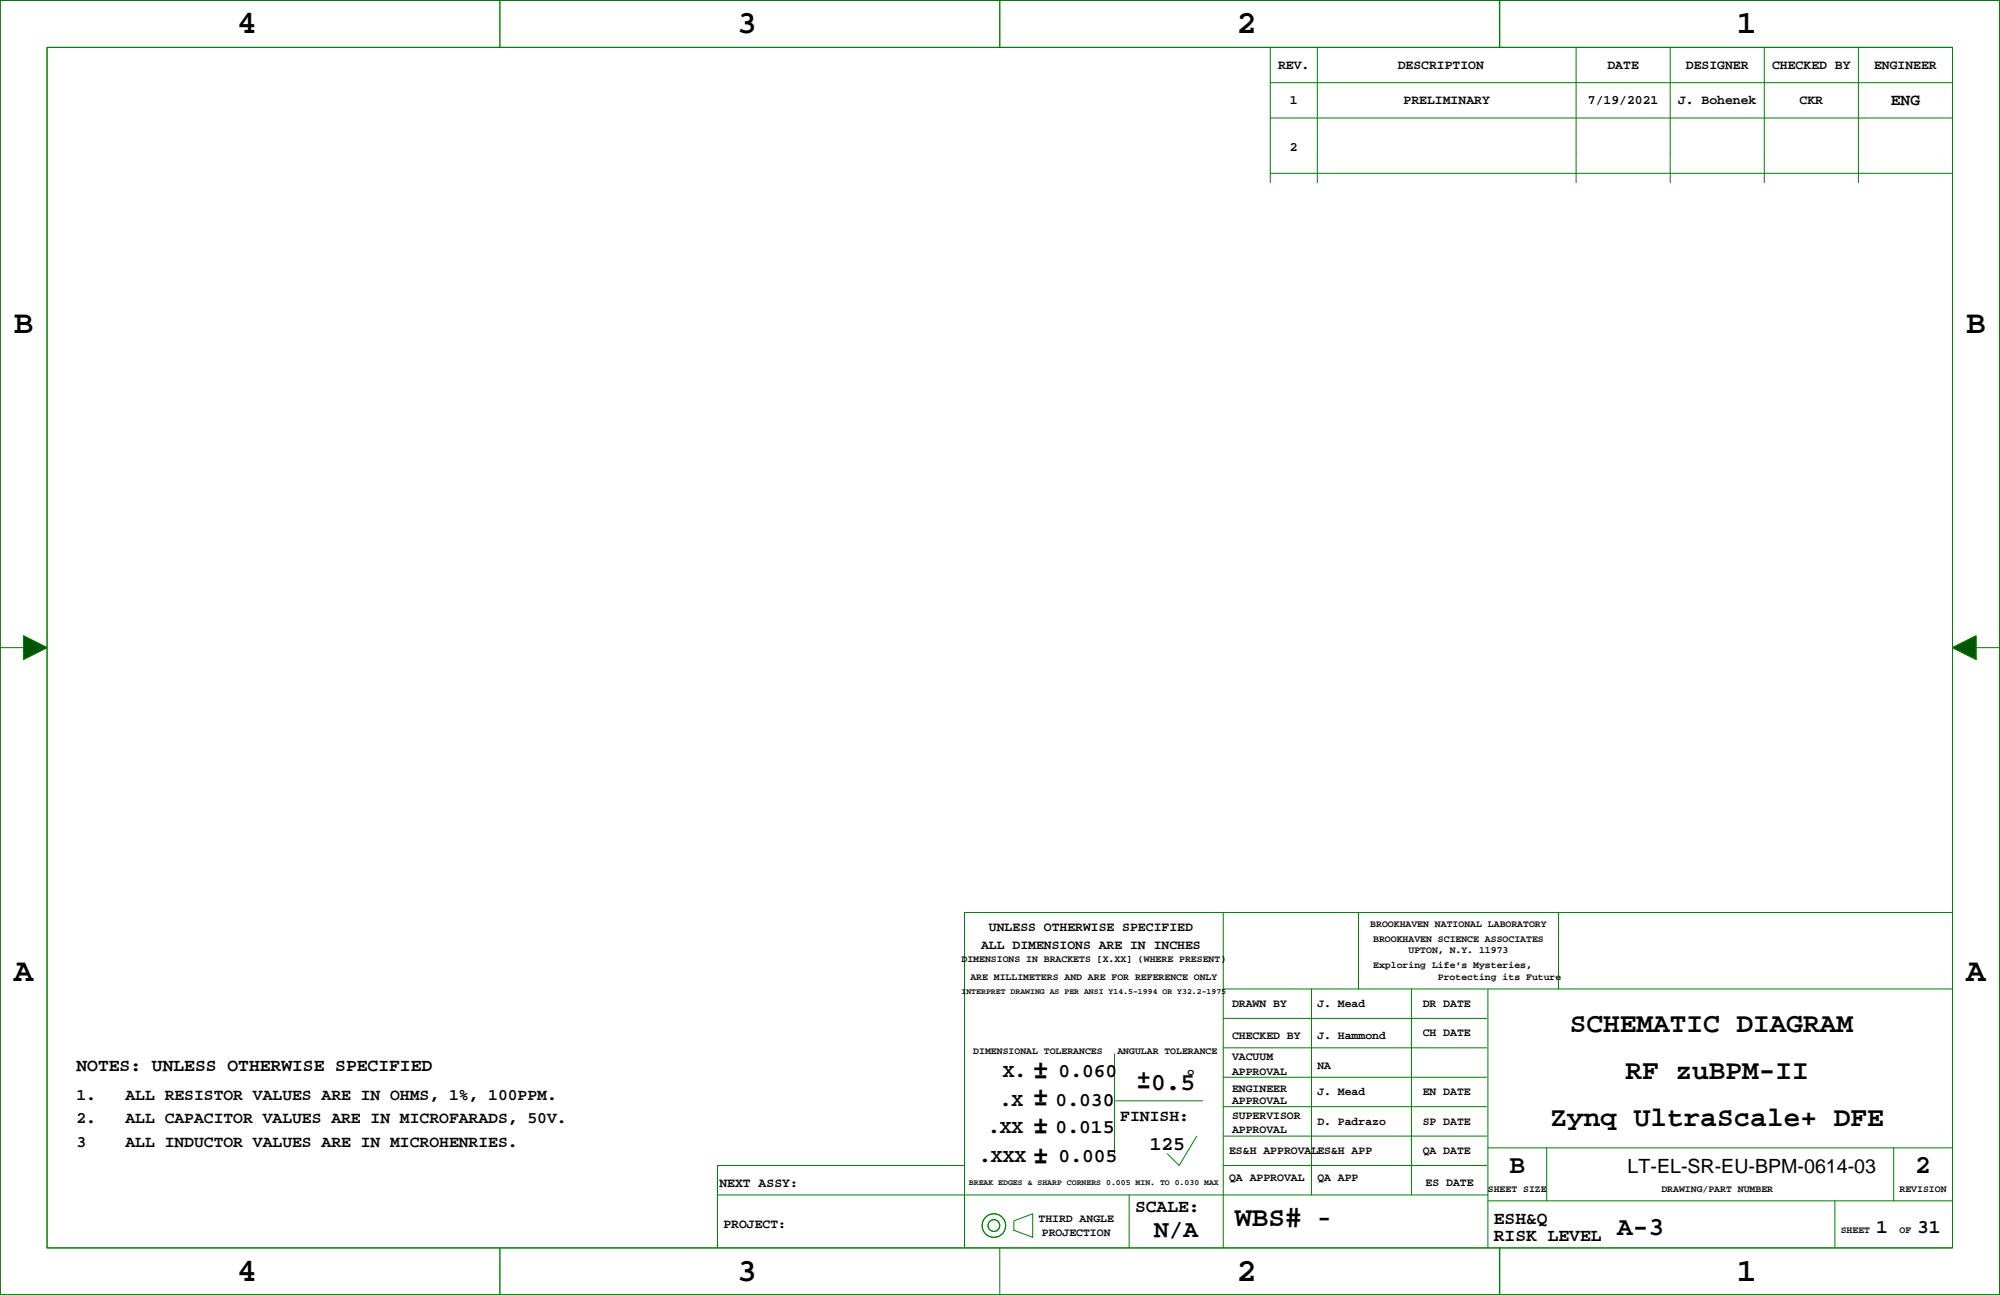
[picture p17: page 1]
DR DATE; ANGULAR TOLERANCE; DIMENSIONAL TOLERANCES; FINISH:; DRAWN BY; SHEET; UPTON, N.Y. 11973; REVISION; ESH&Q RISK LEVEL; WBS#; REV.; DESCRIPTION; DATE; DESIGNER; CHECKED BY; ENGINEER; ARE MILLIMETERS AND ARE FOR REFERENCE ONLY; Protecting its Future; .XXX +- 0.005; SHEET SIZE; SCALE:; THIRD ANGLE PROJECTION; PROJECT:; NEXT ASSY:; ENG; LT-EL-SR-EU-BPM-0614-03; PRELIMINARY; CKR; J. Mead; J. Bohenek

UNLESS OTHERWISE SPECIFIED
ALL DIMENSIONS ARE IN INCHES
DIMENSIONS IN BRACKETS [X.XX] (WHERE PRESENT)
INTERPRET DRAWING AS PER ANSI Y14.5-1994 OR Y32.2-1975

BROOKHAVEN NATIONAL LABORATORY
BROOKHAVEN SCIENCE ASSOCIATES

Exploring Life's Mysteries,

SCHEMATIC DIAGRAM
RF zuBPM-II
Zynq UltraScale+ DFE

CHECKED BY | J. Hammond | CH DATE

VACUUM APPROVAL | NA

NOTES: UNLESS OTHERWISE SPECIFIED
1. ALL RESISTOR VALUES ARE IN OHMS, 1%, 100PPM.
2. ALL CAPACITOR VALUES ARE IN MICROFARADS, 50V.
3 ALL INDUCTOR VALUES ARE IN MICROHENRIES.

ENGINEER APPROVAL | J. Mead | EN DATE

SUPERVISOR APPROVAL | D. Padrazo | SP DATE

ES&H APPROVAL | ES&H APP | QA DATE

BREAK EDGES & SHARP CORNERS 0.005 MIN. TO 0.030 MAX

QA APPROVAL | QA APP | ES DATE

DRAWING/PART NUMBER

# FPGA - Bank 0 & HD Banks

## BANK 44

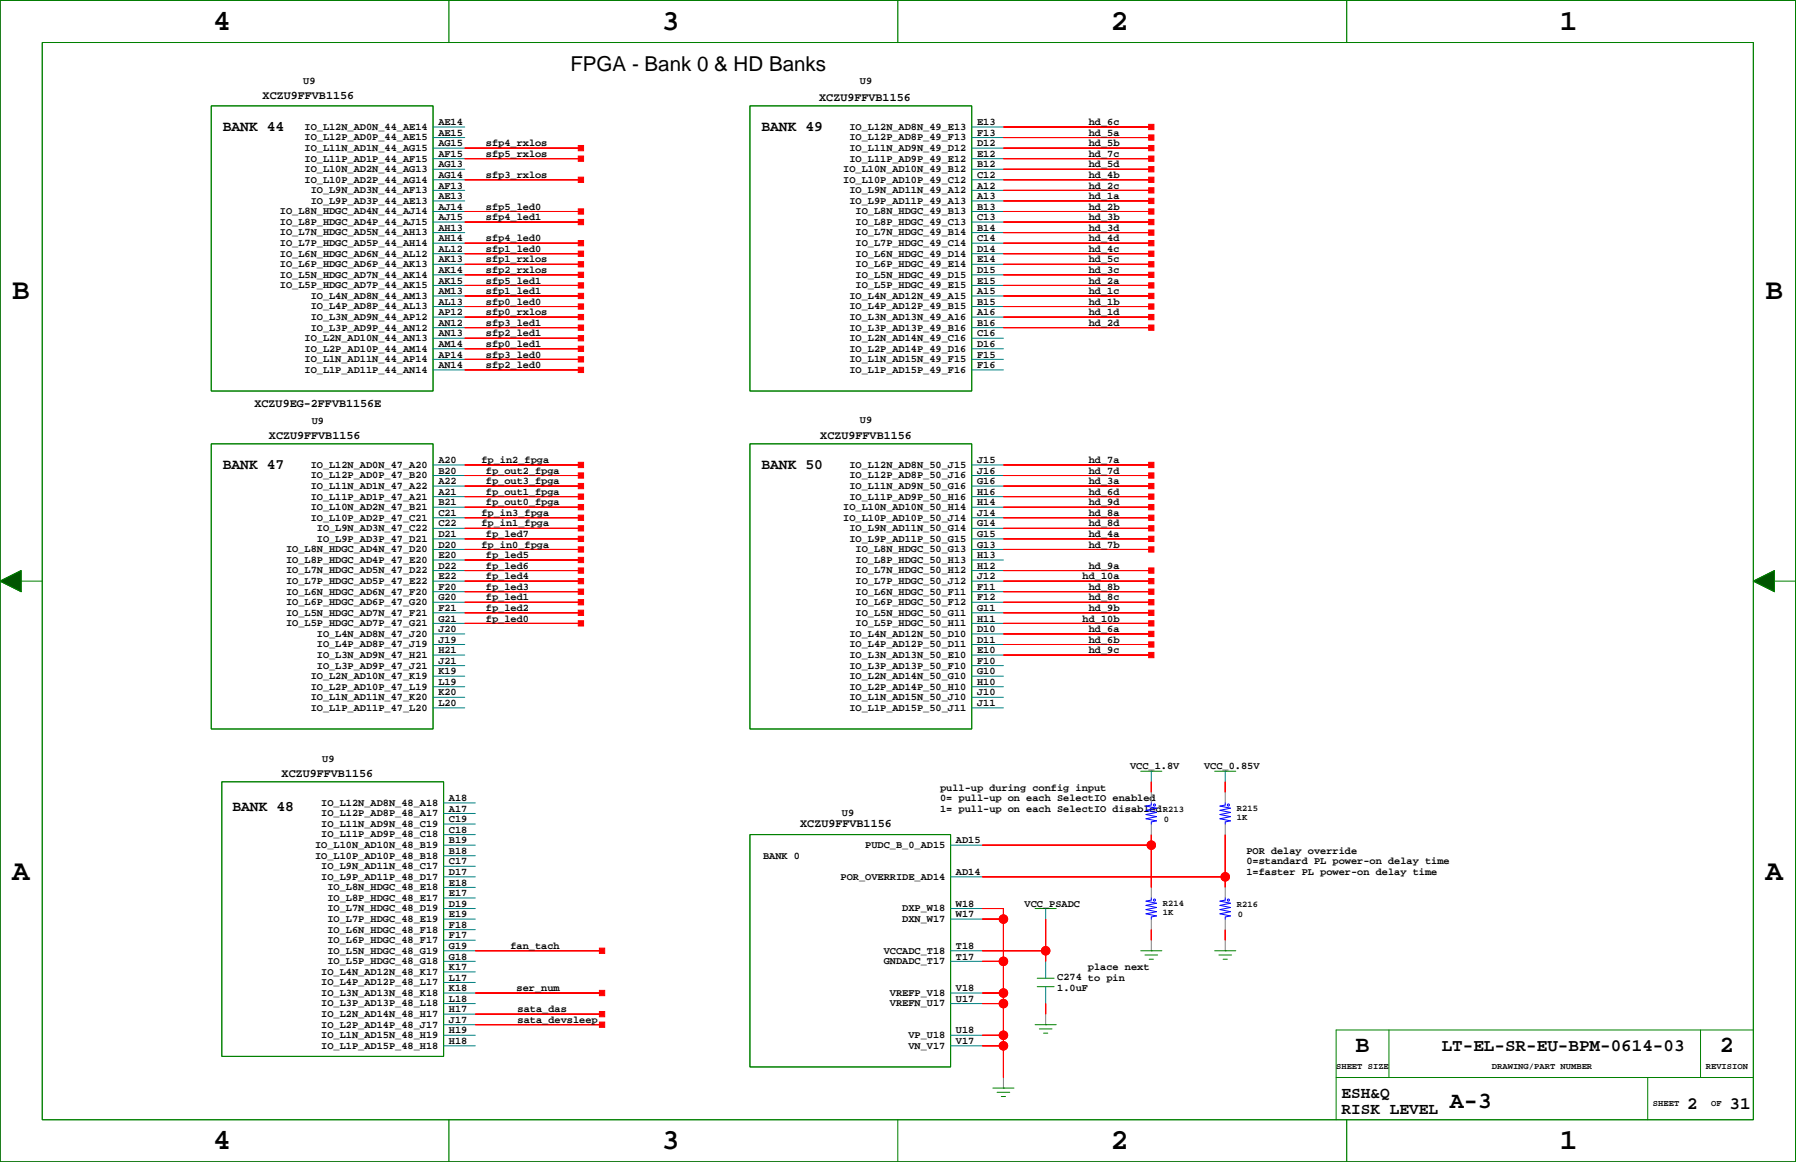
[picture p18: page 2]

pull-up during config input
0= pull-up on each SelectIO enabled
1= pull-up on each SelectIO disabled

POR delay override
0=standard PL power-on delay time
1=faster PL power-on delay time

# FPGA - HP Banks

XCZU9FFVB1156

## BANK 64

VREF_64_AJ11

IO_L1P_T0L_N0_DBC_64_AJ12

IO_L1N_T0L_N1_DBC_64_AK12

IO_L2P_T0L_N2_64_AL11

IO_L2N_T0L_N3_64_AM11

IO_L3P_T0L_N4_AD15P_64_AL10

IO_L3N_T0L_N5_AD15N_64_AM10

IO_L4P_T0U_N6_DBC_AD7P_64_AP11

IO_L4N_T0U_N7_DBC_AD7N_64_AP10

IO_L5P_T0U_N8_AD14P_64_AN9

IO_L5N_T0U_N9_AD14N_64_AP9

IO_L6P_T0U_N10_AD6P_64_AJ10

IO_L6N_T0U_N11_AD6N_64_AK10

IO_T0U_N12_VRP_64_AN11

IO_T1U_N12_64_AJ7

IO_L7P_T1L_N0_QBC_AD13P_64_AN8

IO_L7N_T1L_N1_QBC_AD13N_64_AP8

IO_L8P_T1L_N2_AD5P_64_AM9

IO_L8N_T1L_N3_AD5N_64_AM8

IO_L9P_T1L_N4_AD12P_64_AJ9

IO_L9N_T1L_N5_AD12N_64_AK9

IO_L10P_T1U_N6_QBC_AD4P_64_AN7

IO_L10N_T1U_N7_QBC_AD4N_64_AP7

IO_L11P_T1U_N8_GC_64_AK8

IO_L11N_T1U_N9_GC_64_AK7

IO_L12P_T1U_N10_GC_64_AL8

IO_L12N_T1U_N11_GC_64_AL7

IO_L13P_T2L_N0_GC_QBC_64_AL6

IO_L13N_T2L_N1_GC_QBC_64_AL5

IO_L14P_T2L_N2_GC_64_AM6

IO_L14N_T2L_N3_GC_64_AM5

IO_L15P_T2L_N4_AD11P_64_AP5

IO_L15N_T2L_N5_AD11N_64_AP4

IO_L16P_T2U_N6_QBC_AD3P_64_AN6

IO_L16N_T2U_N7_QBC_AD3N_64_AP6

IO_L17P_T2U_N8_AD10P_64_AM4

IO_L17N_T2U_N9_AD10N_64_AN4

IO_L18P_T2U_N10_AD2P_64_AK5

IO_L18N_T2U_N11_AD2N_64_AK4

IO_T2U_N12_64_AM3

IO_T3U_N12_64_AP1

IO_L19P_T3L_N0_DBC_AD9P_64_AN2

IO_L19N_T3L_N1_DBC_AD9N_64_AP2

IO_L20P_T3L_N2_AD1P_64_AN3

IO_L20N_T3L_N3_AD1N_64_AP3

IO_L21P_T3L_N4_AD8P_64_AM1

IO_L21N_T3L_N5_AD8N_64_AN1

IO_L22P_T3U_N6_DBC_AD0P_64_AL3

IO_L22N_T3U_N7_DBC_AD0N_64_AL2

IO_L23P_T3U_N8_64_AK1

IO_L23N_T3U_N9_64_AL1

IO_L24P_T3U_N10_64_AK3

IO_L24N_T3U_N11_64_AK2

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
AN11
AK10
AJ10
AP9
AN9
AP10
AP11
AM10
AL10
AM11
AL11
AK12
AJ12

AJ11

XCZU9FFVB1156
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

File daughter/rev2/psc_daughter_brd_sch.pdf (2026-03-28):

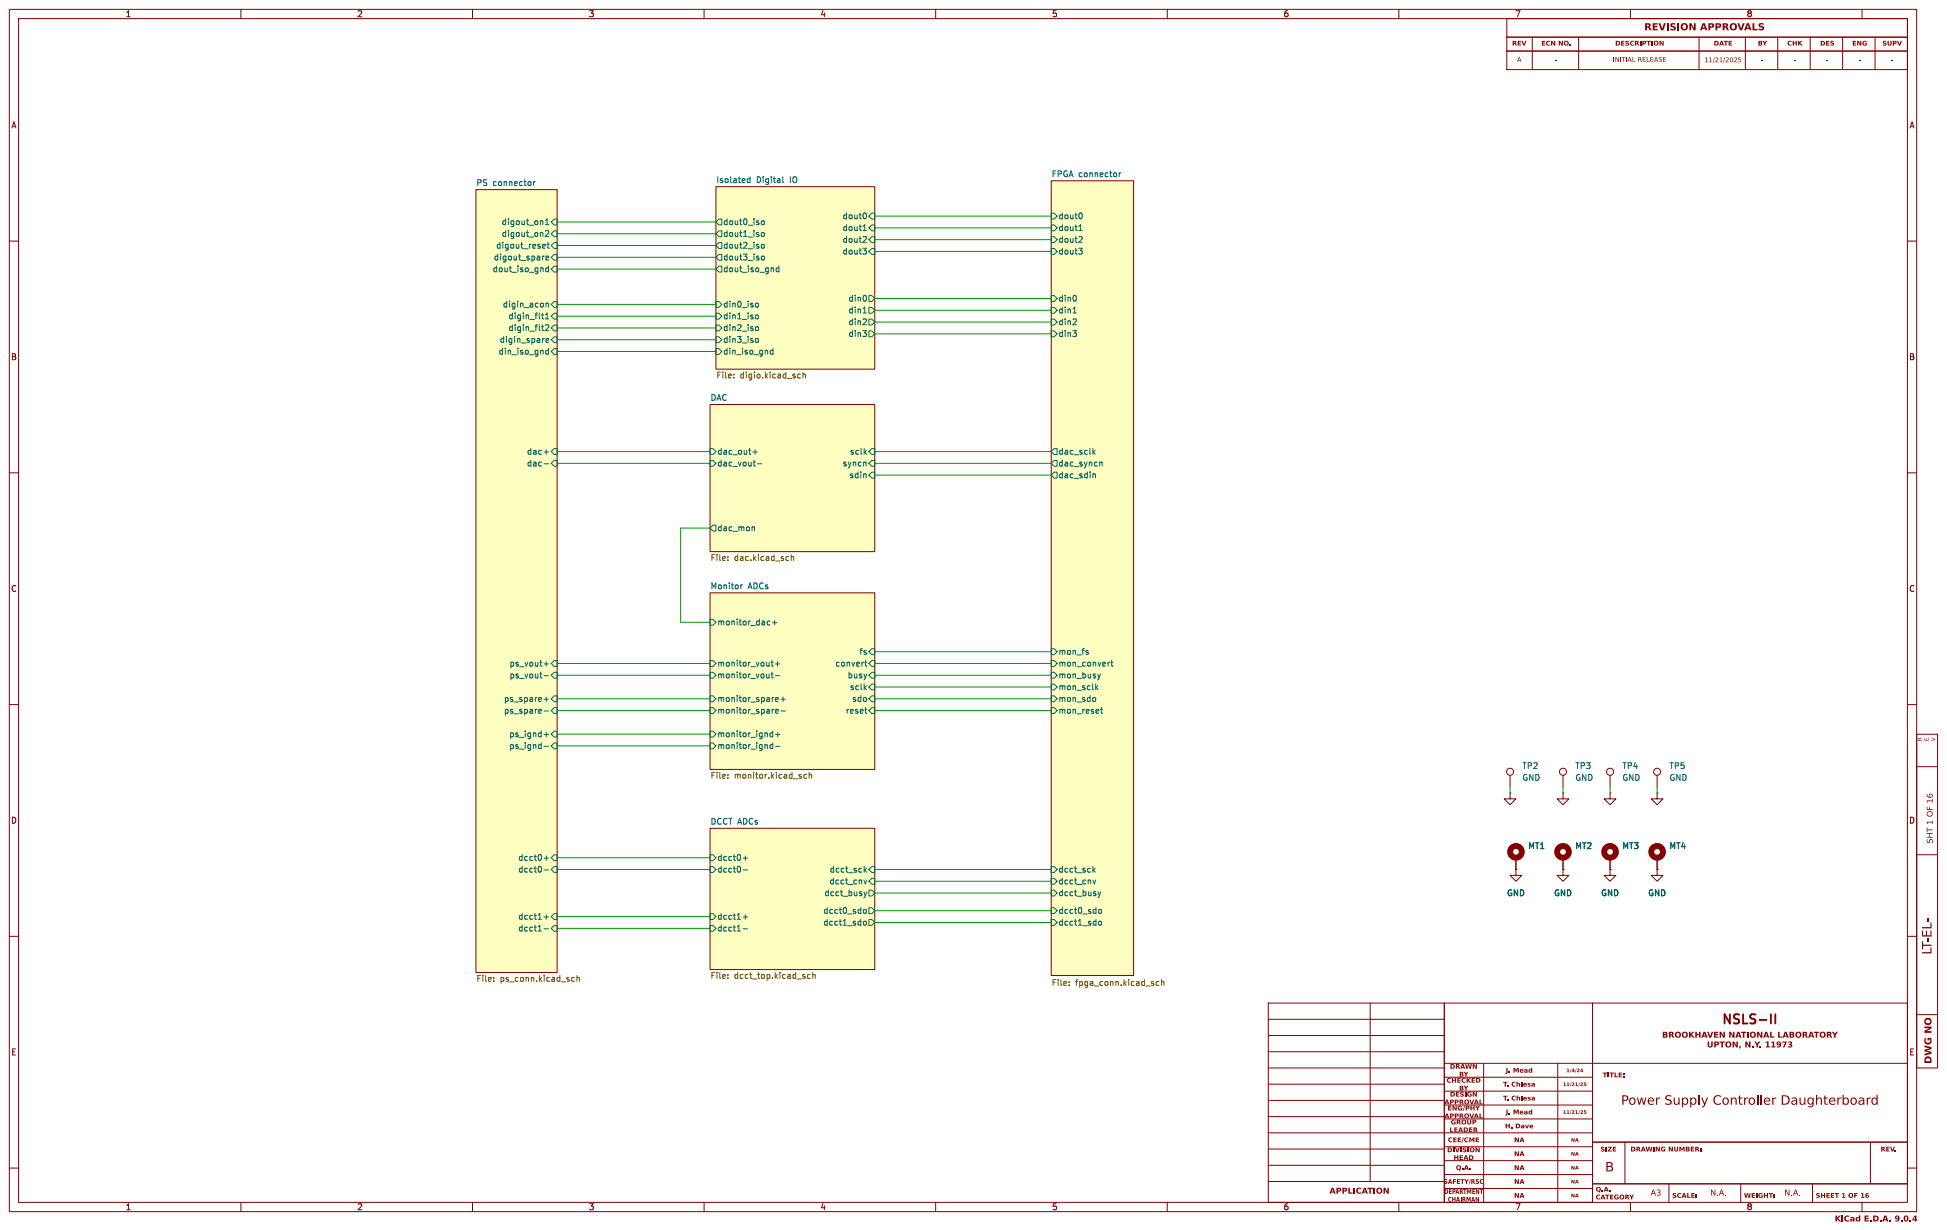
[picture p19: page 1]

REV | ECN NO. - | INITIAL RELEASE REVISION APPROVALS DESCRIPTION | DATE | BY | CHK | DES | ENG | SUPV A

BY CHECKED | J. Mead | 1/4/24 | TITLE:Power Supply Controller Daughterboard
BY DESIGN | T. Chiesa | 11/21/25
APPROVAL ENG/PHY
APPROVAL GROUP

LEADER | J. Mead H. Dave NA | 11/21/25 NA

CEE/CME DIVISION
HEAD Q.A. SAFETY/RSC | NA | NA

SIZE | DRAWING NUMBER: | REV. Q.A.

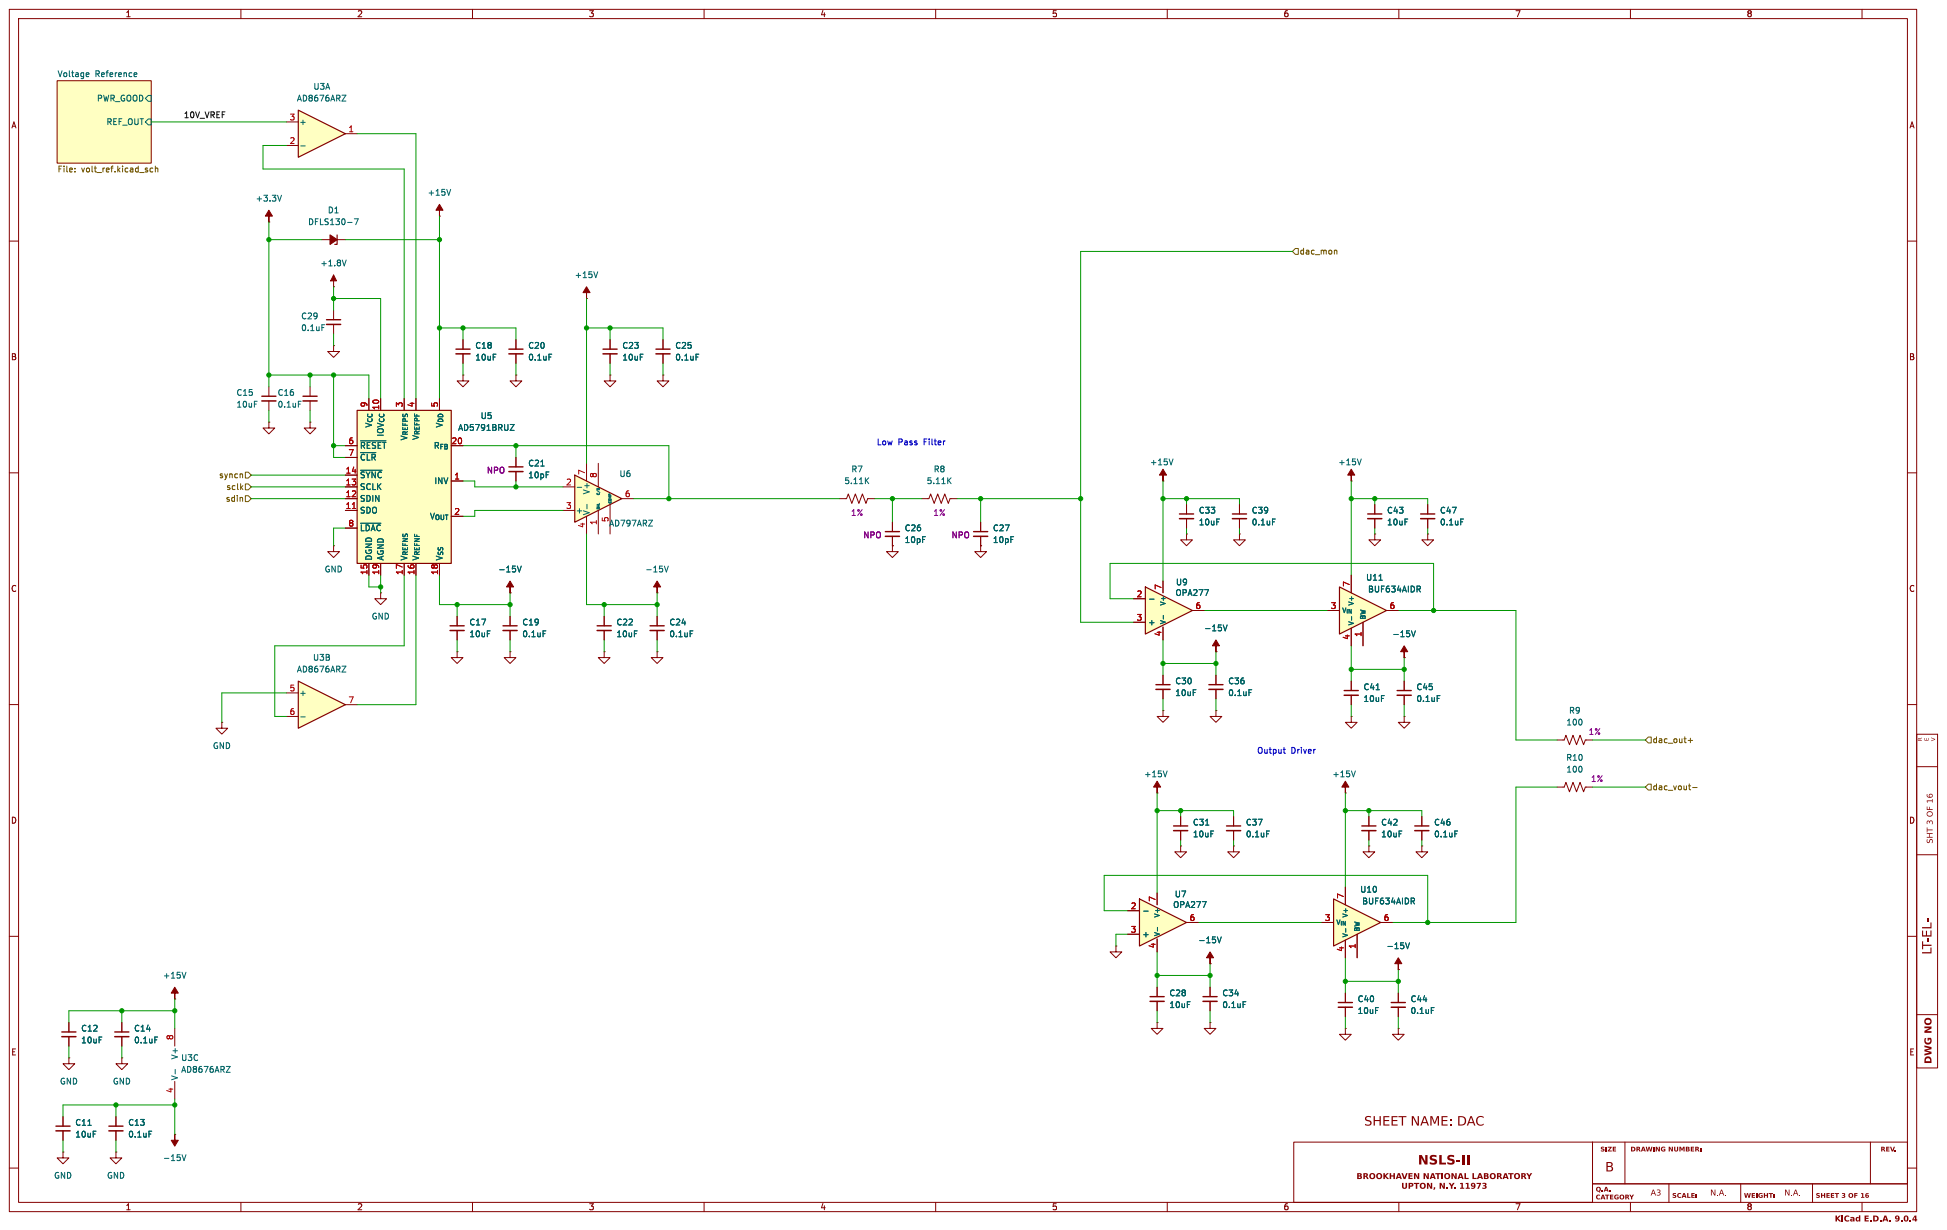
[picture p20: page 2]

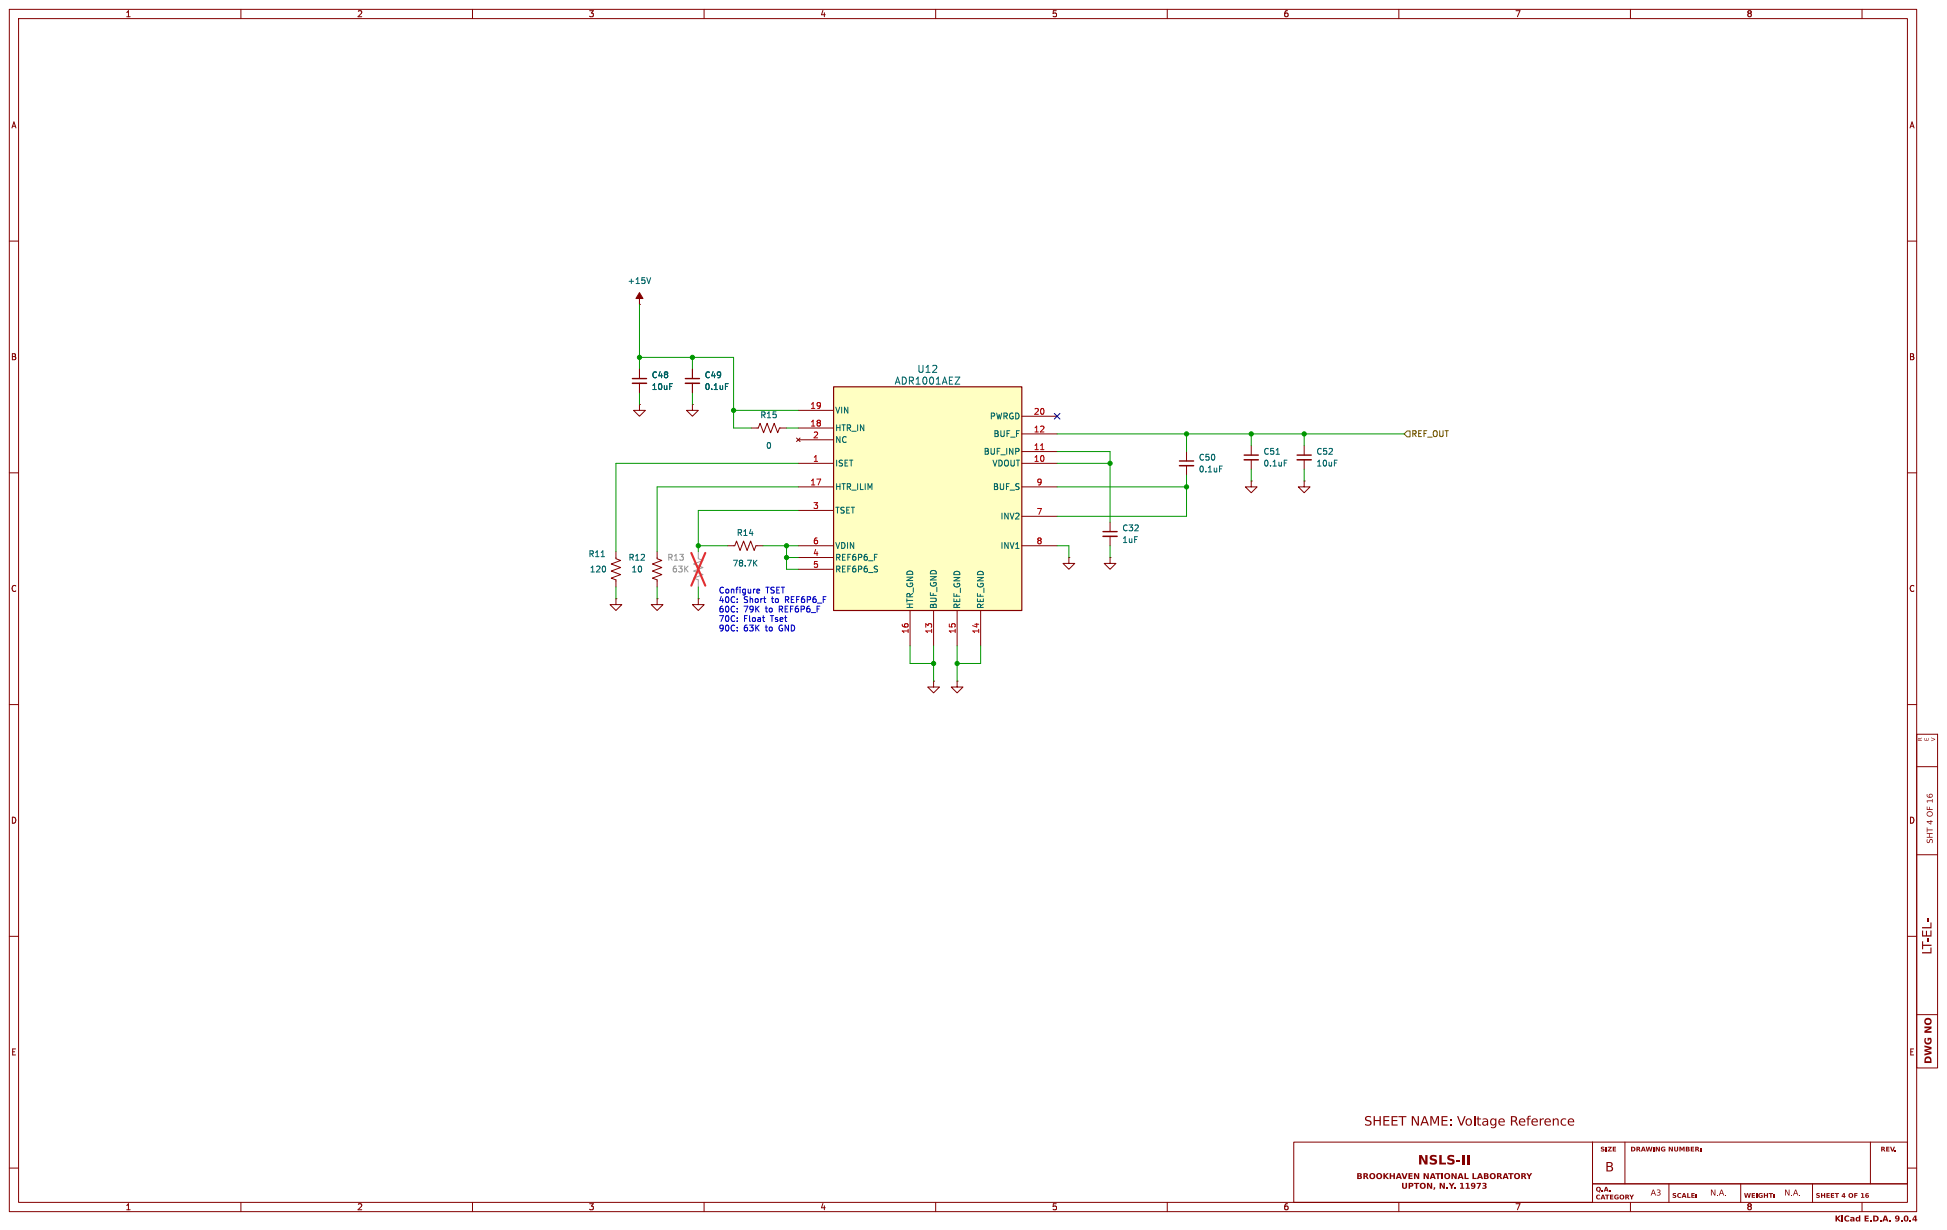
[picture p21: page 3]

40C: Short to REF6P6_F
60C: 79K to REF6P6_F
70C: Float Tset 90C: 63K to GND

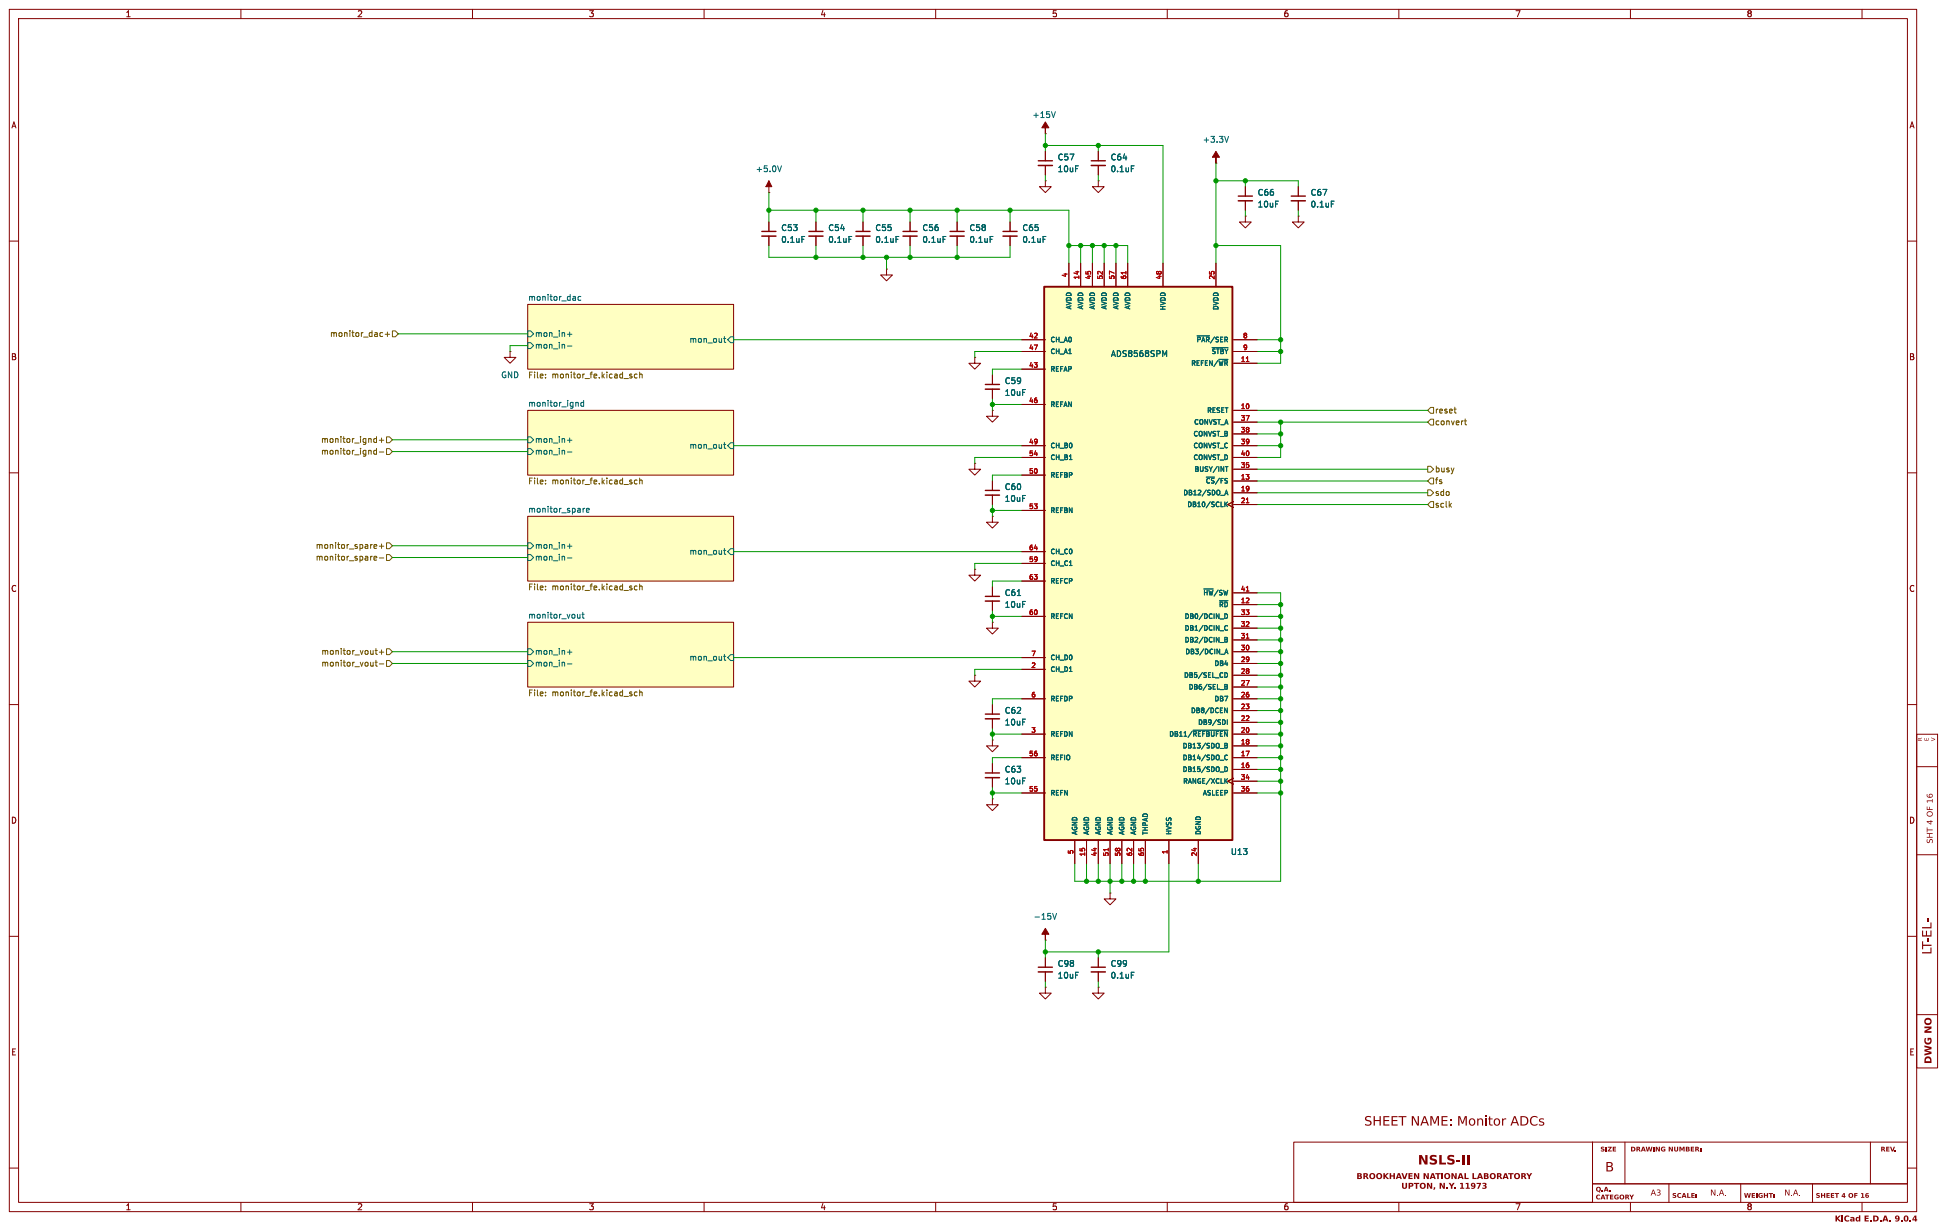
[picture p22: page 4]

1 DGND 24 DVDD 25 ~{PAR}/SER 8 ~{STBY} 9 REFEN/~{WR} 11 RESET 10 CONVST_B 38 CONVST_C 39 CONVST_D 40 BUSY/INT 35 ~{CS}/FS 13 DB12/SDO_A 19 DB10/SCLK 21 ~{HW}/SW 41 ~{RD} 12 DB0/DCIN_D 33 DB1/DCIN_C 32 DB2/DCIN_B 31 DB3/DCIN_A 30 DB4 29 DB5/SEL_CD 28 DB6/SEL_B 27 DB7 26 DB8/DCEN 23 DB9/SDI 22 DB11/~{REFBUFEN} 20 DB13/SDO_B 18 DB14/SDO_C 17 DB15/SDO_D 16 RANGE/XCLK 34 ASLEEP 36 AVDD 14 AGND 15 AVDD 45 AGND 44 AVDD 52 AGND 51 AVDD 57 AGND 58 AVDD 61 AGND 62 THPAD 65 CONVST_A 37 C61

1 DGND 24 DVDD 25 ~{PAR}/SER 8 ~{STBY} 9 REFEN/~{WR} 11 RESET 10 CONVST_B 38 CONVST_C 39 CONVST_D 40 BUSY/INT 35 ~{CS}/FS 13 DB12/SDO_A 19 DB10/SCLK 21 ~{HW}/SW 41 ~{RD} 12 DB0/DCIN_D 33 DB1/DCIN_C 32 DB2/DCIN_B 31 DB3/DCIN_A 30 DB4 29 DB5/SEL_CD 28 DB6/SEL_B 27 DB7 26 DB8/DCEN 23 DB9/SDI 22 DB11/~{REFBUFEN} 20 DB13/SDO_B 18 DB14/SDO_C 17 DB15/SDO_D 16 RANGE/XCLK 34 ASLEEP 36 AVDD 14 AGND 15 AVDD 45 AGND 44 AVDD 52 AGND 51 AVDD 57 AGND 58 AVDD 61 AGND 62 THPAD 65 CONVST_A 37 U13

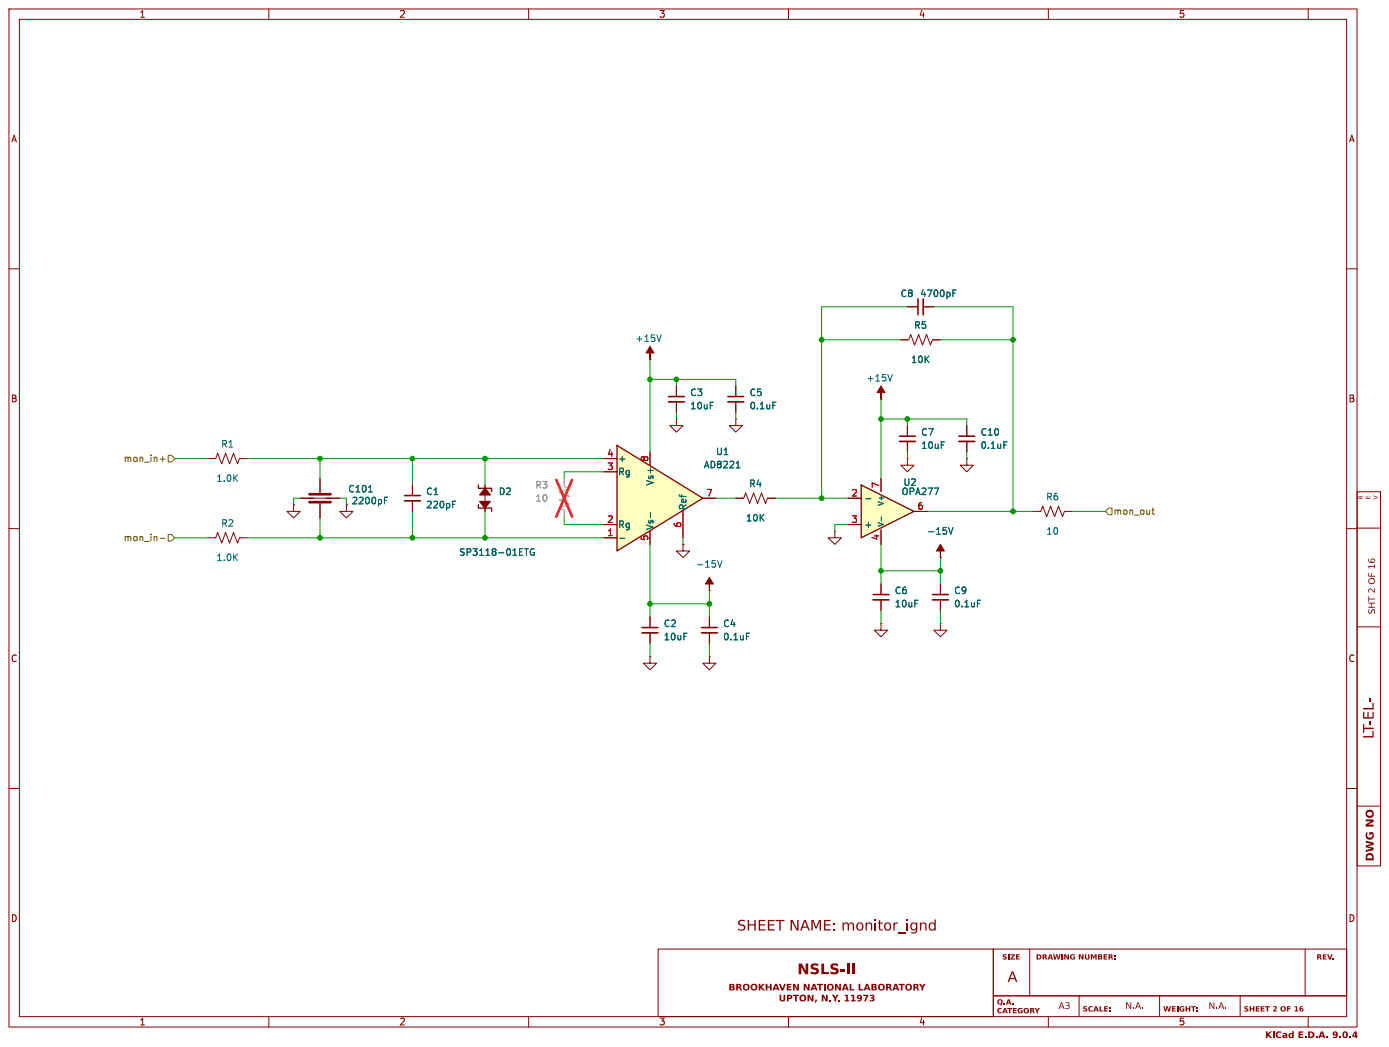
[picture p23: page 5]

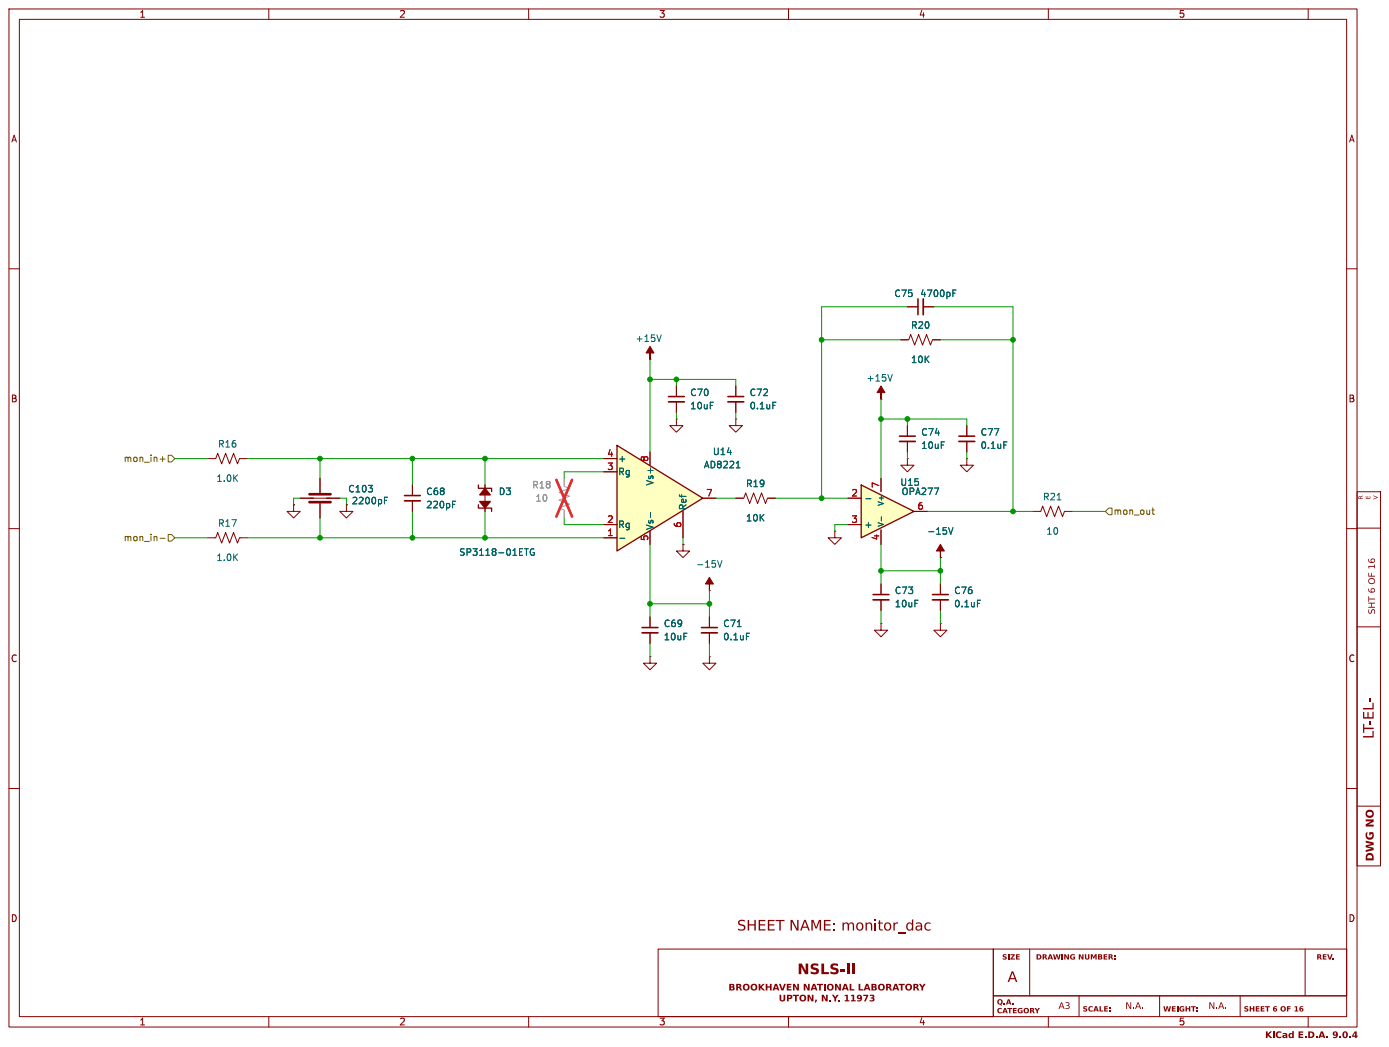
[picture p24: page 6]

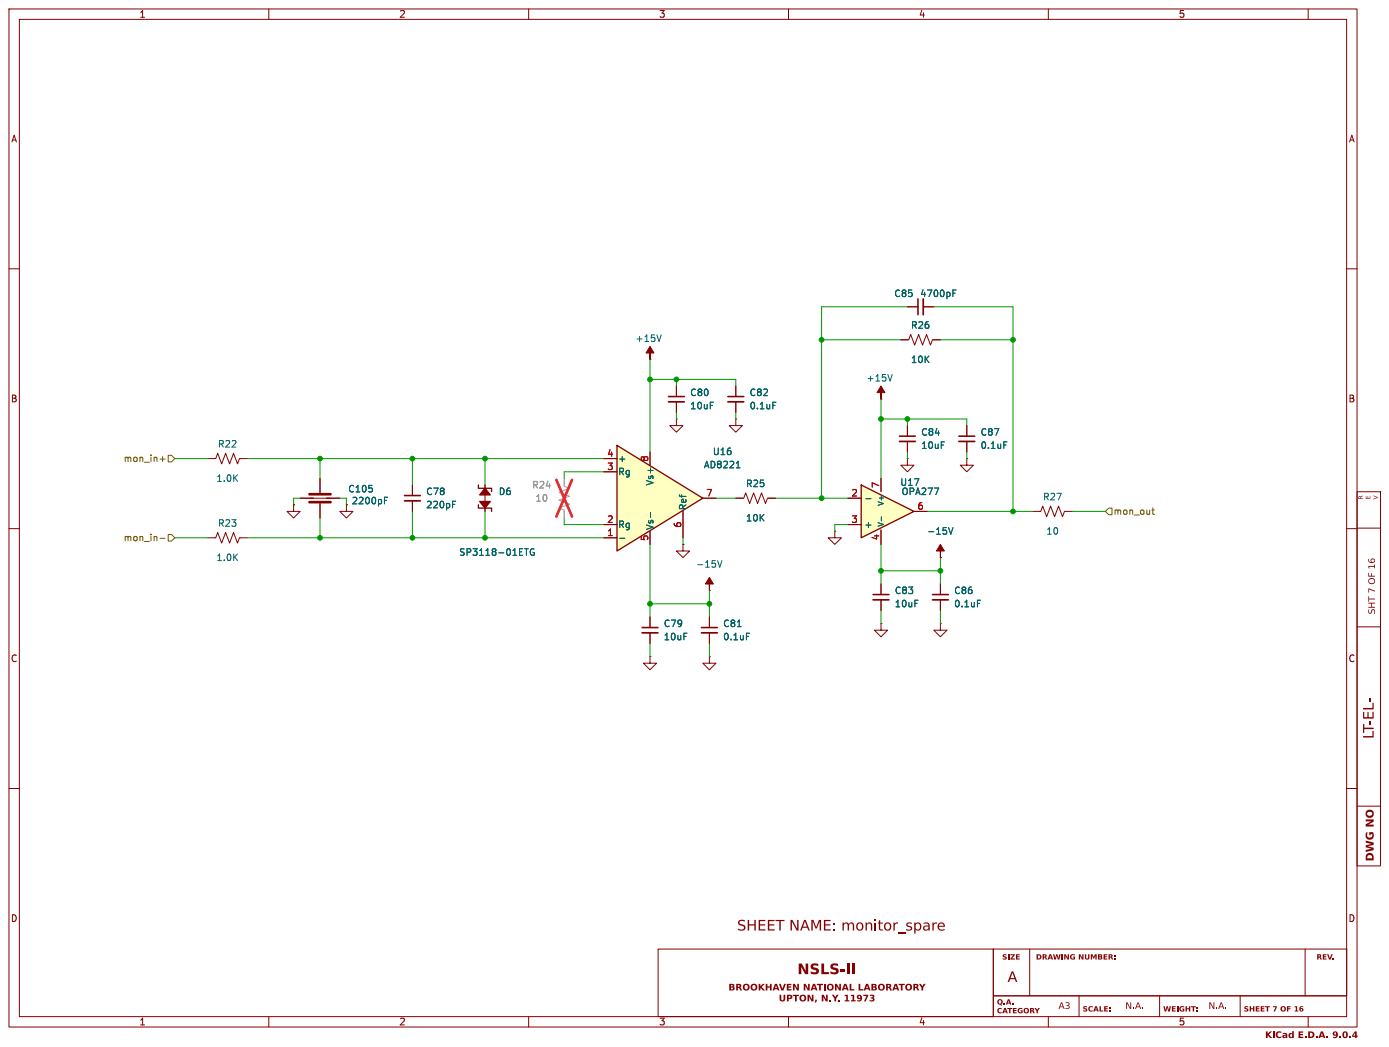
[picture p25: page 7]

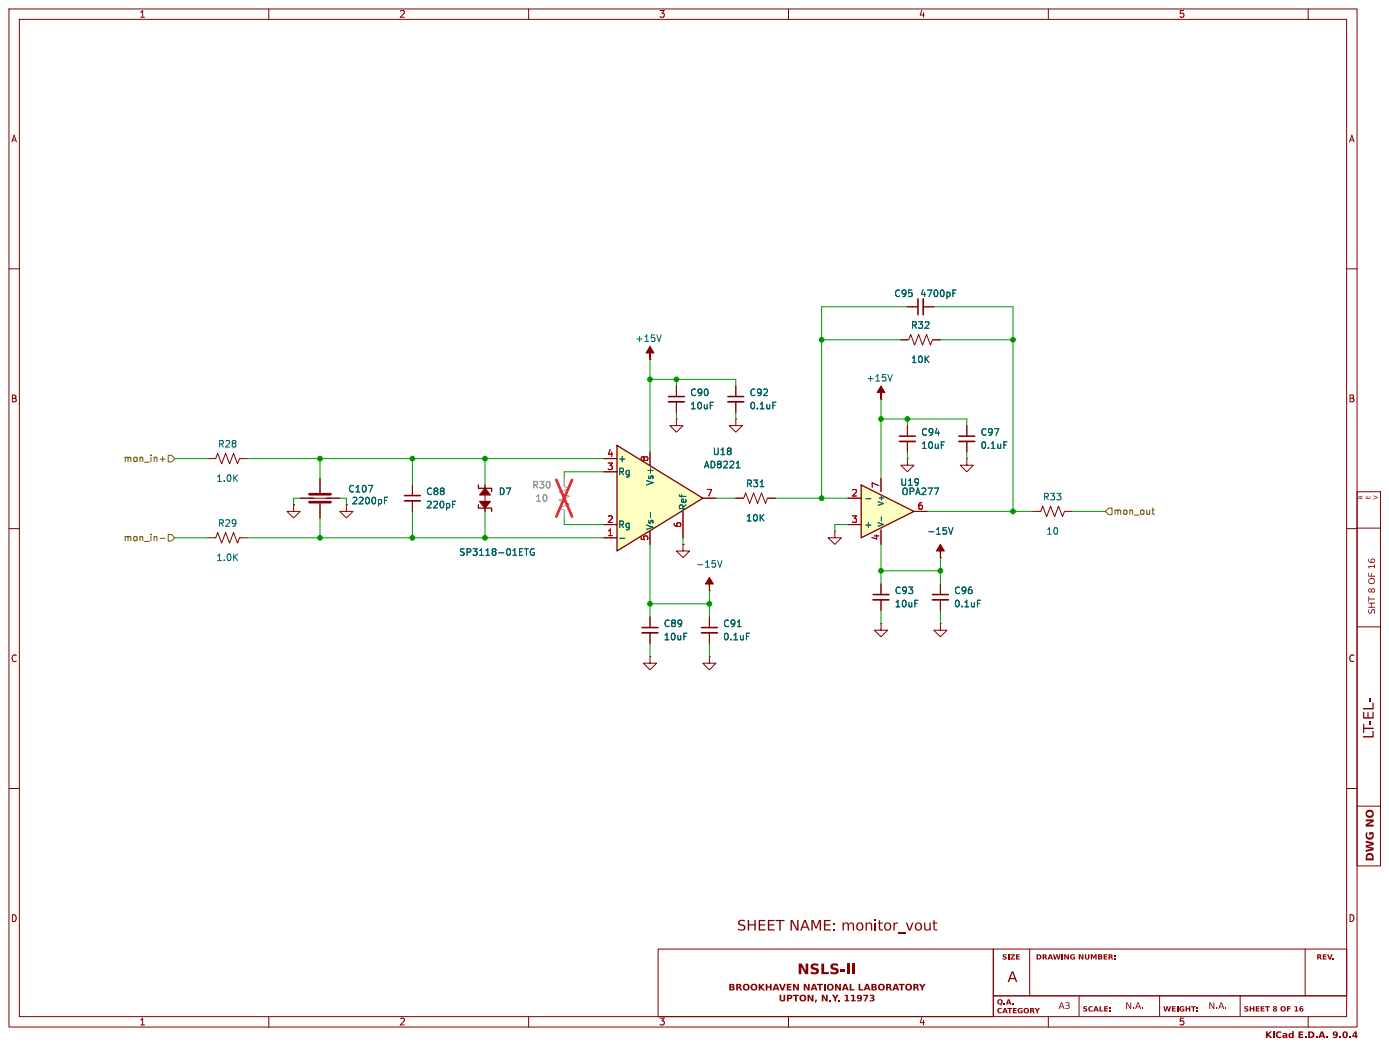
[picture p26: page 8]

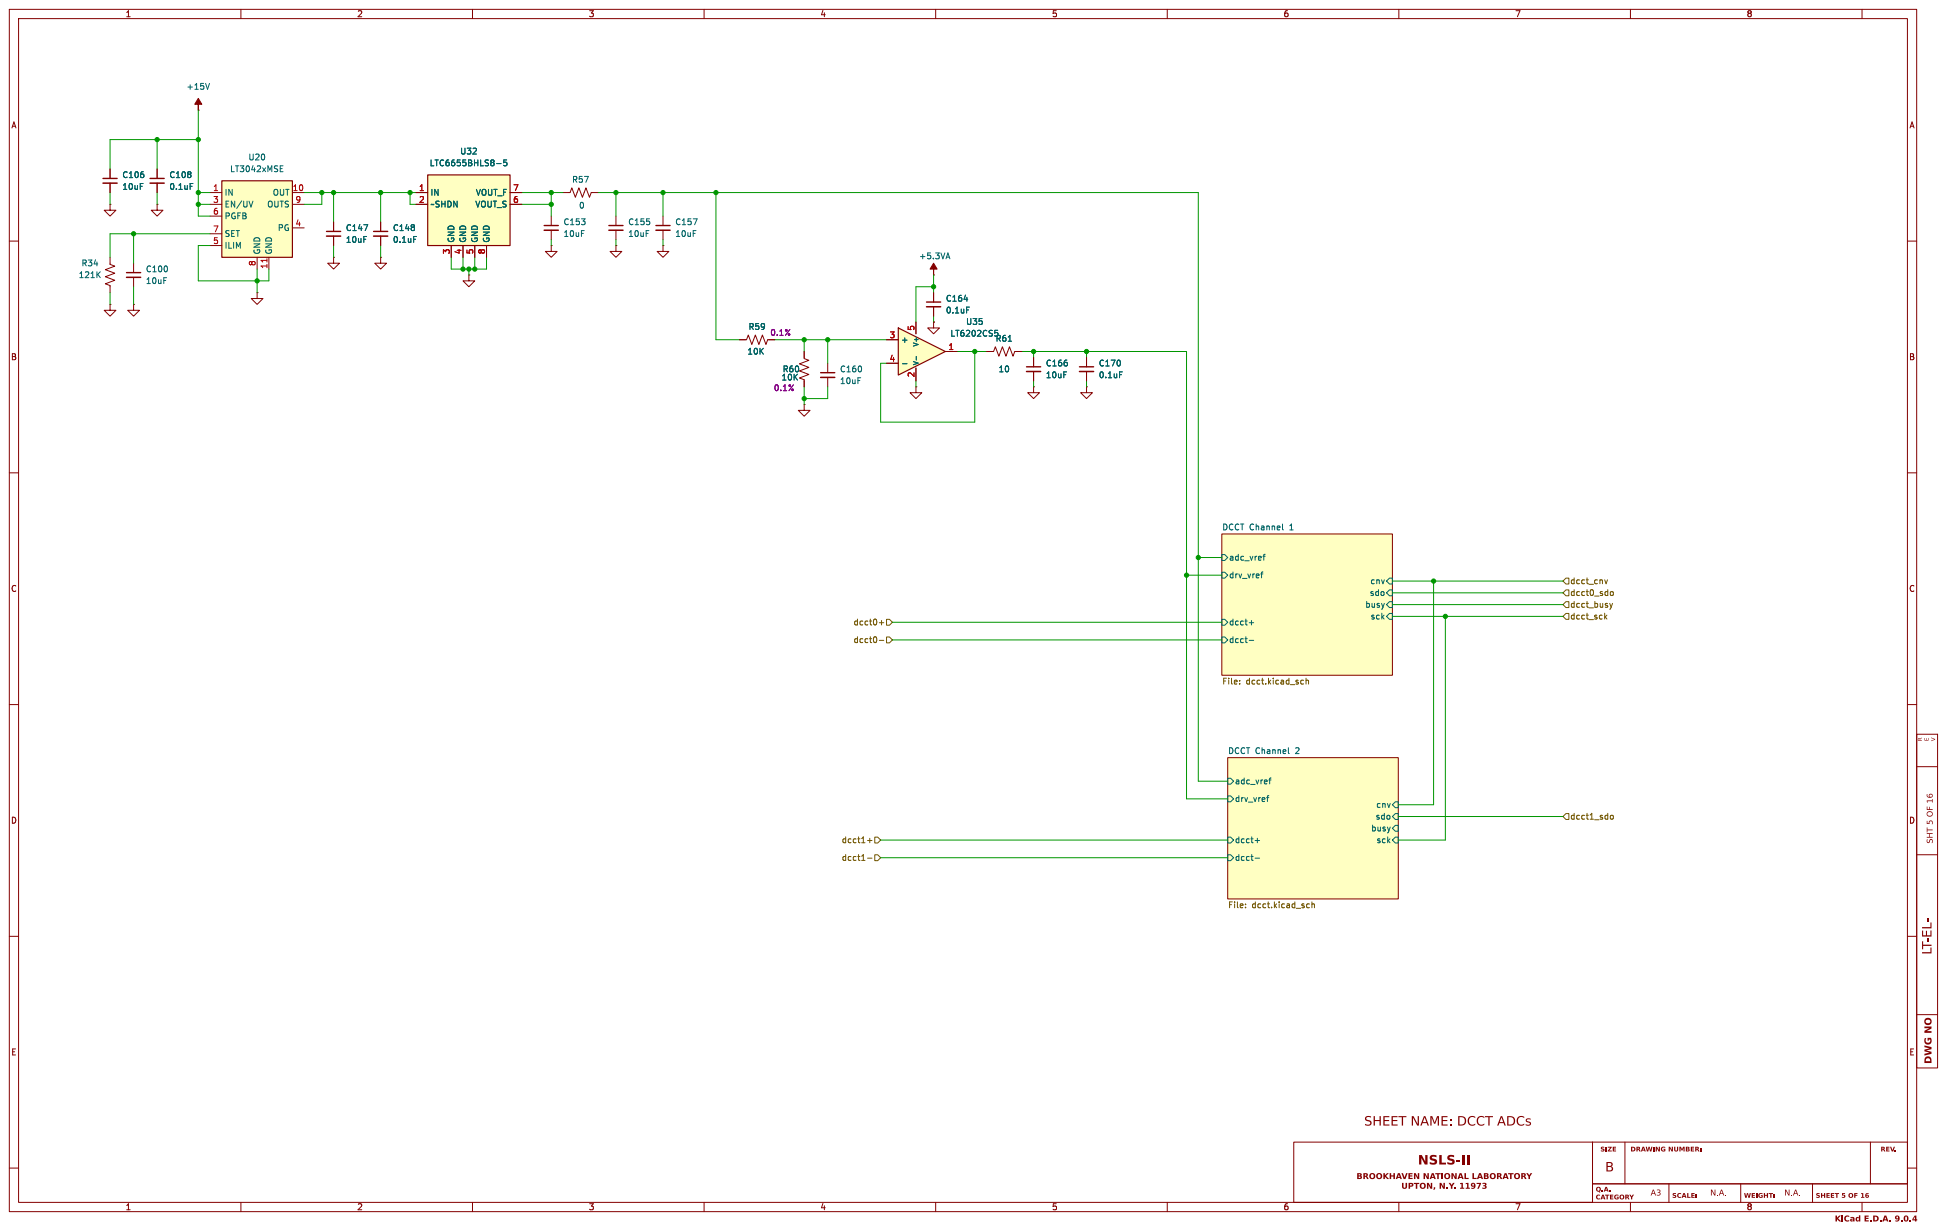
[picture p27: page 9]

8 GND 11 OUT 10 OUTS 9 PG 4 U20

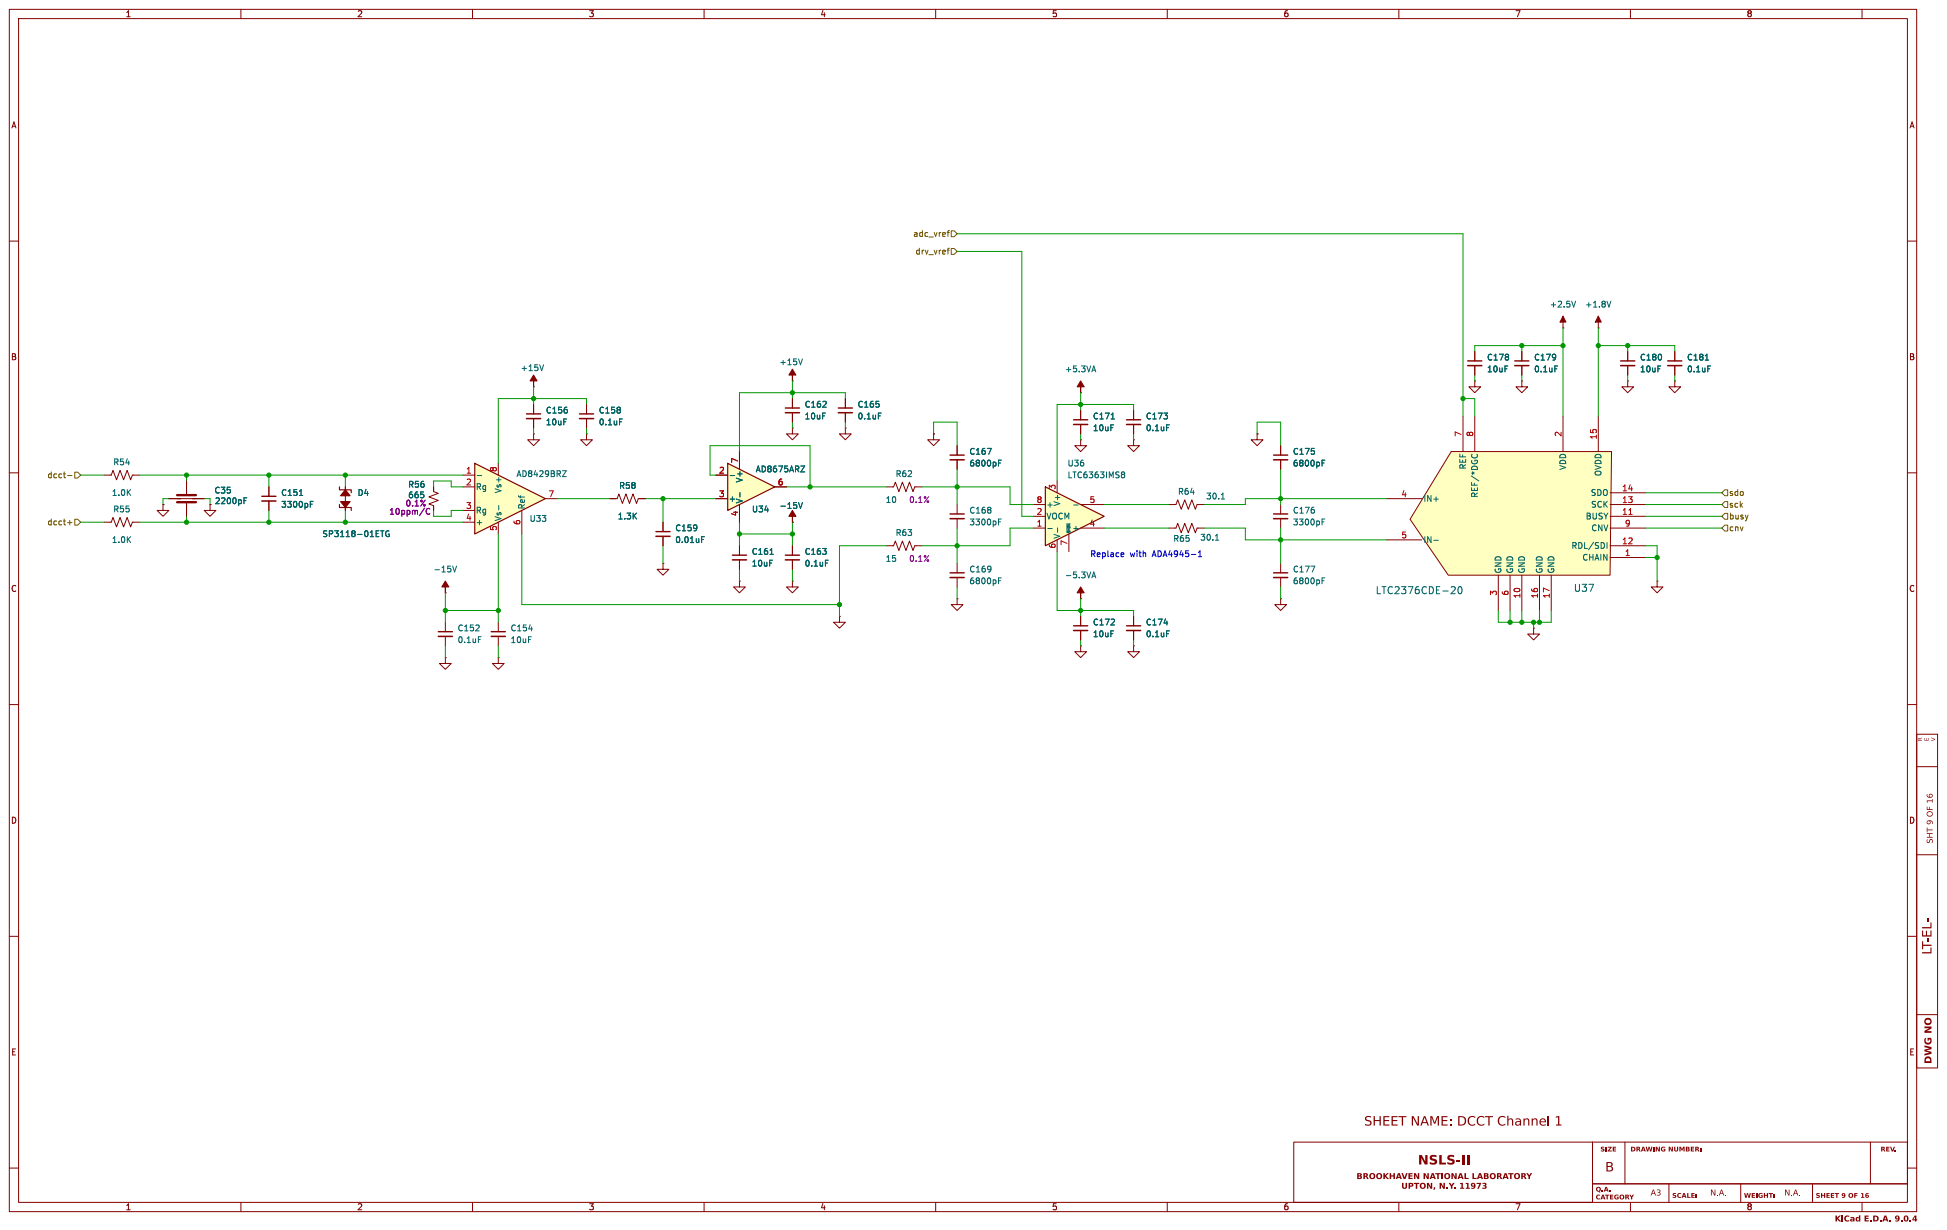
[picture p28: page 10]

6 GND 10 GND 16 GND 17 VDD


6 GND 10 GND 16 GND 17 VDD






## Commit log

2026-03-28 Add board picture
2026-03-28 Edit board picture
2026-03-28 Add KiCad files
    [039301022.step, 3-641215-6-z-3d.step, 39301022.step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]
2026-08-07 added rev1 folder replaced LTC6363-0.5 with ADA4945-1
    [39301022.step, 61082-061400LF--3DModel-STEP-740395.STEP, 61082-061400LF.step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]
2026-08-10 Change adc driver to ADA4945
    [039301022.step, 3-641215-6-z-3d.step, 39301022.step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]
2026-08-10 moved filter caps on dcct schematic added 10pp/C inputs resistors to ADA4945
    [dcct.kicad_sch]
2026-08-10 removed sallen-key for two stage cascade filter on DCCT ADC
    [dcct.kicad_sch]
2026-08-10 updated capacitor values on diff amp
    [dcct.kicad_sch]
2026-08-10 fixed op amp input polarity
    [dcct.kicad_sch]
2026-08-10 fixed input ADC resistors and diff caps
    [dcct.kicad_sch]
2026-08-12 linked ADR1001 to DCCT ADC reference for 5V and 2.5V
    [dac.kicad_sch, dcct.kicad_sch, dcct_top.kicad_sch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]
2026-08-12 replaced ADA4945-1 with THP210DR
    [dcct.kicad_sch]
2026-08-12 fixed diff amp feedback and swapped pins 4 and 5 on THP210
    [dcct.kicad_sch]
2026-08-13 was missing feedback on adc_ref_out page 4
    [volt_ref.kicad_sch]
2026-08-13 added input protection on DCCT stage using BAT54S
    [dcct.kicad_sch]
2026-08-13 added DNP note for cap on ADA4523-1
    [volt_ref.kicad_sch]
2026-08-14 Add Edmundo PS connectors
    [p2.5v.kicad_sch, p5.0vd.kicad_sch, ps_conn.kicad_sch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]
2026-08-14 tied PG high (its a power down pin, not a power good pin)
    [dcct.kicad_sch]
2026-08-14 updated PG pin to PD* pin on THP210DR
    [dcct.kicad_sch]
2026-08-14 DAC fix pin 10 IOvcc was tied to 1.8V should be tied to 3.3V
    [dac.kicad_sch]
2026-08-14 u41 was pulled up to non-existent voltage +1V8 changed +1.8V
    [digin.kicad_sch]
2026-08-17 Finish routing of daughterboard
    [D0008A.stp, dcct.kicad_sch, dcct_top.kicad_sch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]
2026-08-17 Rename versions
    [39301022.step, 61082-061400LF--3DModel-STEP-740395.STEP, 61082-061400LF.step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]
2026-08-18 added gain of 2 op amp for auxillary 10V ref using 0ohm resistor
    [dac.kicad_sch, dcct_top.kicad_sch, psc_daughter_brd.kicad_sch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]
2026-08-30 Rework schematic with separate volt_ref block
    [dac.kicad_sch, dcct.kicad_sch, dcct_top.kicad_sch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]
2026-08-30 Update BOM
    [dac.kicad_sch, dcct.kicad_sch, dcct_top.kicad_sch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]
2026-08-30 Add fiducials
    [psc_daughter_brd.kicad_pcb]
2026-08-31 Add gerbers
    [fpga_conn.kicad_sch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]
2026-09-02 Add parallel resistor for AD8429 gain to be exactly 10
    [dcct.kicad_sch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]
